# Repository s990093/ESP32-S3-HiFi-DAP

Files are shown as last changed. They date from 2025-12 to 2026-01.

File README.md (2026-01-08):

# ESP32-S3 HiFi-DAP 🎵

> **Production-Grade Digital Audio Player**  
> A professional-quality WAV music player built on ESP32 with FreeRTOS dual-core architecture.





---

## ✨ Features

### 🎵 Audiophile Edition Features

- **🎚️ Configurable Bit Depth** - 16/24/32-bit I2S output for maximum DAC compatibility
- **🧠 Dynamic Loudness** - Fletcher-Munson inspired compensation (Bass +8dB at low vol, +2dB at high vol).
- **💎 TPDF Dithering** - Triangular Probability Density Function dithering to eliminate digital quantization distortion.
- **🎚️ 3kHz AIR Treble** - Refined Treble cutoff (3000Hz) for vocal clarity without harshness.
- **🛡️ Anti-Clipping** - 0.7x digital headroom scaler to prevent soft clipping on bass hits.
- **🎯 PCM5102A Optimized** - Tuned for internal PLL usage (SCK->GND) and Charge Pump characteristics.

### 🎯 Core Features

- **🎵 Hybrid Audio Engine** - Native support for **WAV** (16-bit PCM) and **MP3** files
- **🔊 BackgroundAudio Core** - High-performance decoding with I2S DMA offloading
- **📦 Robust File Parsing** - Unified playlist handler for mixed file types
- **💾 Playback Resume** - NVS-based position persistence across power cycles
- **🎚️ Cubic Volume Control** - Enhanced low-volume precision (`vol^3` curve)
- **🔇 Pop-Free Audio** - Fade in/out on play/pause/track changes
- **🎮 Hardware Button Control** - Physical buttons with combo actions (e.g. Loop Toggle)
- **🔁 Loop Control** - Cycle loop modes: Off → Single → All via button combo
- **🚀 Startup Splash** - Animated splash screen on app launch

### 🚀 Advanced Features

- **📦 Modular Architecture** - Clean separation: Config, AudioProcessor, PlaylistManager, ButtonHandler, SerialCommands
- **⚡ FreeRTOS Dual-Core** - Core 0 for UI, Core 1 for audio processing
- **🧠 Smart Memory Management** - Fixed arrays, no heap fragmentation
- **🔍 Serial Command Interface** - Debug and control via UART (30+ commands)
- **📊 Real-Time Monitoring** - Memory usage, playback status, event logging
- **🎛️ Professional Controls** - Volume up/down, prev/next, pause/play

---

## 📋 Table of Contents

- [Desktop App](#-desktop-app-new)
- [Hardware Requirements](#hardware-requirements)
- [Pin Configuration](#pin-configuration)
- [Software Requirements](#software-requirements)
- [Installation](#installation)
- [Usage](#usage)
- [Serial Commands](#serial-commands)
- [Audio Converter Tool](#audio-converter-tool)
- [Technical Architecture](#technical-architecture)
- [Project Structure](#project-structure)
- [Troubleshooting](#troubleshooting)
- [Development](#development)
- [License](#license)

---

## 🖥️ Desktop App (NEW!)

### Apple Music-Inspired Control Center

Manage your ESP32 music player with a beautiful desktop application featuring:

- **🎨 Premium Design** - Glassmorphism, vibrant gradients, Apple Music aesthetics
- **📚 Library Management** - Browse, play, delete, and rename tracks
- **📤 File Upload** - Drag & drop MP3/WAV files to SD card
- **📊 System Diagnostics** - View real-time CPU usage, task states, and memory health (htop-style)
- **💾 Storage Monitor** - Visual SD card usage bar
- **⚡ Auto-connect** - Remembers your device

Desktop App

### Quick Start

```bash
cd desktop-app
npm install
npm start
```

👉 **[Full Desktop App Documentation →](desktop-app/README.md)**

---

## 🔧 Hardware Requirements

### Minimum Requirements

| Component | Specification |
| --- | --- |
| **MCU** | ESP32 (ESP32-WROOM, ESP32-DevKitC) |
| **Flash** | 4MB minimum |
| **SRAM** | 520KB (internal) |
| **SD Card** | Class 10+ (20MHz SPI compatible) |
| **DAC** | PCM5102A (Recommended for Audiophile Mode) |

> **⚠️ PCM5102A Critical Setup**:
> To enable the internal PLL and reduce jitter:
>
> 1. Connect **SCK** pin to **GND**.
> 2. Add **100uF + 0.1uF** capacitors near VCC for deep bass stability.

### Tested Hardware

- ✅ ESP32-DevKitC V4
- ✅ ESP32-WROOM-32D
- ✅ PCM5102A I2S DAC breakout
- ✅ SanDisk Ultra 32GB microSD (Class 10)

### Optional Components

- **Buttons** - 5x tactile switches (VOL+/-, PREV/NEXT, PAUSE)
- **Display** - (Future) TFT/OLED for UI
- **Amplifier** - External amplifier for speakers

---

## 📌 Pin Configuration

### SD Card (SPI)

| Pin  | ESP32 GPIO | Description |
| ---- | --- | --- |
| MISO | GPIO 19 | Data Out |
| MOSI | GPIO 23 | Data In |
| SCK  | GPIO 18 | Clock |
| CS | GPIO 5 | Chip Select |

### I2S DAC

| Pin | ESP32 GPIO | Description |
| --- | --- | --- |
| BCK | GPIO 4 | Bit Clock |
| WS/LRC | GPIO 15 | Word Select (L/R Clock) |
| DATA | GPIO 2 | Serial Data |

### Control Buttons

| Function | ESP32 GPIO | Description |
| --- | --- | --- |
| VOL+ | GPIO 12 | Volume Up (single press +5%, long press +1%) |
| VOL- | GPIO 13 | Volume Down (single press -5%, long press -1%) |
| PREV | GPIO 14 | Previous Track |
| NEXT | GPIO 27 | Next Track |
| PAUSE | GPIO 26 | Pause/Play (double-click = Next) |

> **Note**: All buttons use `INPUT_PULLDOWN` mode with rising edge interrupt.

---

## 💻 Software Requirements

### Development Tools

```bash
# macOS (Homebrew)
brew install arduino-cli
brew install ffmpeg  # For audio conversion

# Python dependencies
pip install rich  # For colorful CLI output
```

### Arduino Libraries (Auto-installed)

- `SPI` v3.3.3
- `SD` v3.3.3
- `FS` v3.3.3
- `Preferences` v3.3.3 (NVS)
- `BackgroundAudio` (Native ESP32 I2S Audio Library)

---

## 🚀 Installation

### 1. Clone Repository

```bash
git clone https://github.com/yourusername/ESP32-S3-HiFi-DAP.git
cd ESP32-S3-HiFi-DAP
```

### 2. Configure Board

```bash
arduino-cli config init
arduino-cli core update-index
arduino-cli core install esp32:esp32
```

### 3. Compile and Upload

```bash
# Using provided upload script
python3 scripts/upload.py src/WavPlayer --board esp32

# Or manually
arduino-cli compile --fqbn esp32:esp32:esp32 src/WavPlayer
arduino-cli upload -p /dev/cu.usbserial-* --fqbn esp32:esp32:esp32 src/WavPlayer
```

### 4. Prepare SD Card

```bash
# Format SD card as FAT32
# Copy WAV files to root directory

# Optional: Convert audio files
python3 scripts/audio_converter.py song.mp3 song.flac
```

### 5. Monitor Serial Output

```bash
python3 scripts/monitor.py /dev/cu.usbserial-* 460800
```

---

## 🎮 Usage

### Button Controls

| Action | Button | Behavior |
| --- | --- | --- |
| **Volume Up** | VOL+ (GPIO12)  | +5% per press, hold for +1%/50ms |
| **Volume Down** | VOL- (GPIO13)  | -5% per press, hold for -1%/50ms |
| **Previous Track** | PREV (GPIO14)  | Jump to previous track |
| **Next Track** | NEXT (GPIO27)  | Jump to next track |
| **Link Toggle** | PREV + NEXT | Hold both for 1s: Toggle Loop One / Loop All |
| **Pause/Play** | PAUSE (GPIO26) | Single press = toggle, double-click = next |

### First Boot

1. Insert SD card with WAV files
2. Power on ESP32
3. Wait for initialization (~3 seconds)
4. Press **PAUSE** button to start playback
5. Adjust volume with **VOL+/VOL-**

### Resume Playback

The player automatically saves:

- Current track position
- Volume level
- Play/pause state

After power cycle, it resumes from the last position.

---

## 🖥️ Serial Commands

Connect via serial terminal (460800 baud) and use these commands:

| Command | Alias | Description |
| --- | --- | --- |
| `mem` | `memory` | Show memory usage (heap, PSRAM) with visual bars |
| `tasks` | `tasks_json` | Show FreeRTOS task stats (CPU%, Stack, State) |
| `status` | `s` | Display current playback state |
| `bitdepth <n>` | - | Set I2S output bit depth (16/24/32) |
| `save` | - | Manually save playback position to NVS |
| `resume` | - | Restore playback position from NVS |
| `help` | `h`, `?` | Show command list |

### Example: Memory Status

```
mem

╔════════════════════════════════════════╗
║         Memory Status                  ║
╚════════════════════════════════════════╝
HEAP Memory:
  Total:      361400 bytes
  Used:       127416 bytes (35.3%)
  Free:       233984 bytes (64.7%)
  Min Free:   233000 bytes
  Usage: [███████░░░░░░░░░░░░░] 35.3%

PSRAM: Not available
```

---

## 🎨 Audio Converter Tool

Convert audio files to ESP32-compatible WAV format:

### Basic Usage

```bash
# Convert to WAV (default)
python3 scripts/audio_converter.py song.mp3

# Convert to FLAC (lossless archive)
python3 scripts/audio_converter.py song.mp3 --format flac

# Batch convert
python3 scripts/audio_converter.py *.mp3 --format wav
```

### Supported Formats

**Input**: MP3, M4A, AAC, FLAC, WAV, OGG, WMA, APE, ALAC  
**Output**:

- **WAV** - 16-bit PCM, 44.1kHz stereo (ESP32 playback)
- **FLAC** - Lossless, 44.1kHz stereo (archival)

See [Audio Converter Guide](docs/audio_converter_guide.md) for details.

---

## 🏗️ Technical Architecture

### FreeRTOS Dual-Core Design

```
┌─────────────────────────────────────────────────────┐
│                    ESP32 (Dual-Core)                │
├───────────────────────────┬─────────────────────────┤
│    Core 0 (Protocol CPU)  │  Core 1 (Application CPU)│
│   ┌─────────────────────┐ │ ┌──────────────────────┐│
│   │  Button Handler     │ │ │  Audio Playback      ││
│   │  - ISR Processing   │ │ │  - SD Card Reading   ││
│   │  - State Management │ │ │  - WAV Decoding      ││
│   │  - Serial Commands  │ │ │  - Volume Control    ││
│   │  - UI Updates       │ │ │  - I2S Streaming     ││
│   └─────────────────────┘ │ └──────────────────────┘│
│          Priority: 1       │       Priority: 2       │
└───────────────────────────┴─────────────────────────┘
                      │
              ┌───────┴────────┐
              │  Shared State  │
              │  (Mutex-locked)│
              └────────────────┘
```

### Audio Pipeline

```
SD Card → Chunk Parser → Volume Control → Fade In/Out → I2S DMA → DAC → Headphones/Speakers
         (20MHz SPI)    (Logarithmic)    (2048 samples)  (8x1024)
```

### Key Technologies

- **BackgroundAudio Lib** - Core decoding engine for MP3/WAV
- **Chunk-Based Feeding** - Efficient buffer management
- **Cubic Volume Curve** - `pow(vol, 3)` calculation for 10-bit dynamic range
- **NVS (Non-Volatile Storage)** - Flash-based state persistence
- **Hybrid Task Pattern** - Core 0 (UI/Control) + Core 1 (Audio Decoding)

---

## 📁 Project Structure

```
ESP32-S3-HiFi-DAP/
├── src/
│   └── WavPlayer/
│       ├── WavPlayer.ino          # Main firmware (~350 lines)
│       ├── Config.h               # Global configuration
│       ├── AudioProcessor.h/.cpp  # EQ, dithering, bit depth
│       ├── PlaylistManager.h/.cpp # Playlist scanning
│       ├── ButtonHandler.h/.cpp   # Button ISRs, NVS
│       └── SerialCommands.h/.cpp  # Serial interface
├── desktop-app/                   # 🆕 Desktop Control Center
│   ├── src/
│   │   ├── main.js                # Electron main process
│   │   ├── renderer.js            # UI logic (383 lines)
│   │   ├── styles.css             # Apple-style CSS (600+ lines)
│   │   ├── index.html             # Main interface
│   │   └── demo.html              # Standalone demo
│   ├── package.json
│   └── README.md                  # Desktop app docs
├── scripts/
│   ├── audio_converter.py         # Audio format converter
│   ├── upload.py                  # Build & upload tool
│   └── monitor.py                 # Serial monitor
├── docs/
│   ├── architecture.md            # System architecture
│   ├── wav_player_guide.md        # User guide
│   └── audio_converter_guide.md   # Converter manual
└── README.md                      # This file
```

---

## 🐛 Troubleshooting

### SD Card Not Detected

```
❌ SD Card failed!
```

**Solutions**:

1. Check wiring (MISO/MOSI/SCK/CS)
2. Ensure SD card is FAT32 formatted
3. Try reducing SPI speed to 10MHz in code:
   ```cpp
   SD.begin(SD_CS, SPI, 10000000);  // Change from 20MHz
   ```

### Audio Stuttering

**Causes**:

- Slow SD card (< Class 10)
- Corrupted WAV file
- Insufficient power supply

**Solutions**:

1. Use Class 10+ SD card
2. Re-convert WAV files:
   ```bash
   python3 scripts/audio_converter.py file.wav
   ```
3. Connect 5V/1A power supply (not USB)

### No Audio Output

**Check**:

1. DAC connections (BCK, WS, DATA)
2. DAC power supply (3.3V or 5V depending on model)
3. Headphone/speaker connection
4. Volume level (`status` command should show > 0%)

### Playback Not Resuming

```bash
# Reset NVS storage
save   # First save current state
resume # Then restore
```

If issue persists, reflash ESP32.

---

## 🛠️ Development

### Debug Mode

Enable detailed logging in `WavPlayer.ino`:

```cpp
#define DEBUG_ENABLED 1  // Set to 0 to disable
```

Output includes:

- WAV chunk parsing details
- File scanning progress
- Task creation status
- Event logs for all actions

### Performance Tuning

```cpp
// Adjust DMA buffer for lower latency
.dma_buf_count = 4,    // Default: 8
.dma_buf_len = 512,    // Default: 1024

// Increase SPI speed (if stable)
SD.begin(SD_CS, SPI, 40000000);  // 40MHz (risky)
```

### Adding New Features

1. **EQ (Equalizer)** - Apply DSP filters in `applyVolume()`
2. **Shuffle Mode** - Randomize `playlist[]` order
3. **Gapless Playback** - Pre-buffer next track
4. **Display Support** - Add TFT/OLED in `buttonHandlerTask`

---

## 📊 Performance Metrics

| Metric | Value |
| --- | --- |
| Flash Usage | 486KB (15.4%) |
| SRAM Usage | 30KB (9.3%) |
| Boot Time | ~3 seconds |
| Track Change Latency | <100ms |
| Button Response | <10ms (ISR) |
| Audio Latency | ~46ms (buffer) |
| Max Tracks Supported | 32 (configurable) |

---

## 🤝 Contributing

Contributions welcome! Please:

1. Fork the repository
2. Create a feature branch (`git checkout -b feature/amazing-feature`)
3. Commit changes (`git commit -m 'Add amazing feature'`)
4. Push to branch (`git push origin feature/amazing-feature`)
5. Open a Pull Request

---

## 📄 License

This project is licensed under the MIT License - see [LICENSE](LICENSE) file for details.

---

## 🙏 Acknowledgments

- **Espressif** - ESP32 platform and Arduino core
- **Hackaday** - I2S configuration reference
- **FreeRTOS** - Real-time operating system
- Community contributors and testers

---

## 📞 Contact

**Project**: [ESP32-S3-HiFi-DAP](https://github.com/yourusername/ESP32-S3-HiFi-DAP)  
**Issues**: [GitHub Issues](https://github.com/yourusername/ESP32-S3-HiFi-DAP/issues)  
**Documentation**: [Wiki](https://github.com/yourusername/ESP32-S3-HiFi-DAP/wiki)

---

<p align="center">
  Made with ❤️ for audiophiles and makers
</p>

<p align="center">
  <sub>If you found this project useful, please consider giving it a ⭐!</sub>
</p>

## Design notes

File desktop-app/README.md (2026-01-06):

# ESP32 Music Center - Desktop App 🎵

> **Apple Music-Inspired Control Center for ESP32 HiFi-DAP**  
> A beautiful Electron-based desktop application for managing your ESP32 music player.





---

## ✨ Features

### 🎨 Premium Apple Music Design

- **Glassmorphism Effects** - Backdrop blur and translucent layers
- **Vibrant Gradients** - Purple-pink-blue accent colors
- **Premium Typography** - Inter font (SF Pro-like)
- **Smooth Animations** - Micro-interactions and transitions
- **Enhanced Player Bar** - 120px tall with album art and progress bar

### 🎮 Music Management

- 📚 **Library View** - Browse all tracks on SD card
- ▶️ **Playback Controls** - Play, pause, next, previous
- 📤 **File Upload** - Drag & drop MP3/WAV files
- 🗑️ **File Management** - Delete and rename tracks
- 📊 **Real-time Status** - Track info, volume, system stats

### 🔧 Device Control

- 🔌 **Auto-Connect** - Remembers last connected device
- 📡 **Serial Communication** - 460800 baud UART
- 💾 **SD Storage Monitor** - Visual storage usage bar
- ⚙️ **Settings Panel** - Configure buffer size and preferences

---

## 📸 Screenshots

### Main Interface

Full Interface

### Hover Effects

Hover State

---

## 🚀 Quick Start

### Prerequisites

```bash
# Install Node.js (v16+)
brew install node    # macOS
# Or download from https://nodejs.org

# Verify installation
node --version
npm --version
```

### Installation

```bash
# Navigate to desktop-app directory
cd desktop-app

# Install dependencies
npm install

# Start the application
npm start
```

---

## 📋 Usage Guide

### First Launch

1. **Connect ESP32**

   - Plug in your ESP32 via USB
   - The app will auto-scan for serial ports
   - Select your device and click "Connect"

2. **Browse Library**

   - The library view shows all tracks on SD card
   - Click any track to start playback
   - Hover to see delete button

3. **Upload Music**
   - Switch to "Upload" view
   - Drag & drop MP3/WAV files
   - Or click to browse files

### Controls

| Action | Method |
| --- | --- |
| **Play Track** | Click on track in library |
| **Play/Pause** | Click center play button (⏸/▶) |
| **Next Track** | Click next button (⏭) |
| **Previous Track**  | Click previous button (⏮) |
| **Delete Track** | Hover track → Click 🗑️ button |
| **Rename Track** | Double-click track name → Edit → Enter |
| **Upload File** | Drag & drop to upload zone |
| **Refresh Library** | Click "🔄 Refresh List" |

---

## 🏗️ Architecture

### Tech Stack

- **Framework**: Electron (v39.2.7)
- **IPC**: Serial communication via SerialPort
- **UI**: HTML5 + Vanilla CSS + JavaScript
- **Font**: Inter (Google Fonts)
- **Design**: Apple Music-inspired glassmorphism

### File Structure

```
desktop-app/
├── src/
│   ├── main.js          # Electron main process
│   ├── preload.js       # Context bridge
│   ├── renderer.js      # UI logic (383 lines)
│   ├── index.html       # Main UI
│   ├── styles.css       # Apple-style CSS (600+ lines)
│   └── demo.html        # Standalone demo
├── package.json
└── README.md            # This file
```

### Serial Protocol

The app communicates with ESP32 via JSON commands:

```javascript
// Status Request
"status_json"

// Response
{
  "state": "playing",
  "file": "/song.mp3",
  "track_index": 2,
  "track_total": 15,
  "volume": 35
}

// File List Request
"list_json"

// Response
{
  "files": [
    {"name": "/song1.mp3", "size": 5242880},
    {"name": "/song2.mp3", "size": 7340032}
  ]
}
```

---

## 🎨 Design System

### Color Palette

```css
/* Dark Background */
--bg-primary: #0a0a0f;
--bg-secondary: #1a1a24;

/* Glassmorphism */
--glass-bg: rgba(30, 30, 45, 0.7);
backdrop-filter: blur(40px);

/* Vibrant Accents */
--accent-gradient: linear-gradient(
  135deg,
  #667eea 0%,
  #764ba2 50%,
  #f093fb 100%
);
```

### Typography

```css
font-family: "Inter", -apple-system, BlinkMacSystemFont, "Segoe UI";
-webkit-font-smoothing: antialiased;
letter-spacing: -0.3px to -0.5px;
```

### Animations

- **Fade In**: 0.5s ease on page load
- **Slide Up**: 0.3s for modals
- **Pulse**: 2s infinite for play indicator
- **Glow**: 3s infinite for album art
- **Hover Scale**: 0.2s cubic-bezier for buttons

---

## 🛠️ Development

### Running in Dev Mode

```bash
# Install dependencies
npm install

# Start with hot reload (if using electron-reloader)
npm start

# Or run directly
npx electron .
```

### Building for Production

```bash
# Package for macOS
npx electron-packager . "ESP32 Music Center" --platform=darwin --arch=x64

# Package for Windows
npx electron-packager . "ESP32 Music Center" --platform=win32 --arch=x64

# Package for Linux
npx electron-packager . "ESP32 Music Center" --platform=linux --arch=x64
```

### Debug Mode

Open DevTools with:

- **macOS**: `Cmd + Option + I`
- **Windows/Linux**: `Ctrl + Shift + I`

---

## 🐛 Troubleshooting

### App Won't Start

```bash
# Clear node_modules and reinstall
rm -rf node_modules package-lock.json
npm install
npm start
```

### Serial Port Not Found

1. Check USB connection
2. Verify ESP32 is powered on
3. Click "Rescan" in connection modal
4. Check permissions (macOS may require):
   ```bash
   sudo chmod 666 /dev/cu.usbserial-*
   ```

### Upload Fails

- Ensure ESP32 is connected and idle
- Check SD card has free space
- Try smaller files first (\<10MB)
- Reduce upload chunk size in `main.js`:
  ```javascript
  const CHUNK_SIZE = 4096; // Default: 8192
  ```

### No Status Updates

1. Check serial baud rate (should be 460800)
2. Verify ESP32 firmware supports JSON commands
3. Monitor serial output in DevTools console

---

## 📡 Serial Commands Reference

| Command | Response | Description |
| --- | --- | --- |
| `status_json` | JSON | Current playback status |
| `list_json` | JSON | File list with sizes |
| `sys_json` | JSON | System stats (heap, uptime) |
| `info_json` | JSON | Device info (name, version) |
| `play <file>` | - | Play specific file |
| `pause` | - | Pause playback |
| `resume` | - | Resume playback |
| `next` | - | Next track |
| `prev` | - | Previous track |
| `delete <file>` | - | Delete file from SD |
| `rename <old> <new>` | - | Rename file |
| `upload <path> <size>` | READY | Start file upload |

---

## 🎯 Features Roadmap

### v2.0 (Current)

- ✅ Apple Music-inspired design
- ✅ Glassmorphism effects
- ✅ File upload/delete/rename
- ✅ Real-time status updates
- ✅ SD storage monitoring

### v2.1 (Planned)

- [ ] Album artwork display
- [ ] Seekbar functionality
- [ ] Volume slider control
- [ ] Playlist management
- [ ] Dark/Light theme toggle

### v3.0 (Future)

- [ ] Bluetooth streaming control
- [ ] EQ settings panel
- [ ] Lyrics display
- [ ] Multi-device support
- [ ] Cloud sync

---

## 🤝 Contributing

Contributions are welcome! To contribute:

1. Fork the repository
2. Create a feature branch
3. Make your changes
4. Test on macOS/Windows/Linux
5. Submit a pull request

### Code Style

- Use 2-space indentation
- Follow existing naming conventions
- Add comments for complex logic
- Test serial communication thoroughly

---

## 📄 License

MIT License - see [LICENSE](../LICENSE) file for details.

---

## 🙏 Credits

- **Design Inspiration**: Apple Music
- **Icons**: Unicode emoji
- **Font**: Inter by Rasmus Andersson
- **Framework**: Electron by GitHub

---

<p align="center">
  Made with ❤️ for ESP32 audiophiles
</p>

<p align="center">
  <sub>Part of the ESP32-S3-HiFi-DAP project</sub>
</p>

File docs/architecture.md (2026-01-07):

# ESP32-S3 Hi-Fi Digital Audio Player - System Architecture

> **Version:** 2.1
> **Last Updated:** 2026-01-06
> **Device:** TTGO T-Display S3 (ESP32-S3) / Classic ESP32

## 1. System Overview (系統總覽)

This project implements a high-fidelity digital audio player (DAP) capabilities on the ESP32 platform. It features a unique **Hybrid Bluetooth Architecture** that allows it to function as both a device scanner (central) and a high-quality audio source (A2DP Source) seamlessly.

### Key Features

- **Dual-Core Processing**: Dedicated cores for Audio/Bluetooth (Core 1) and System/UI (Core 0).
- **Hybrid Bluetooth**: Intelligent coexistence between GAP Scanning and A2DP Streaming.
- **High-Resolution Audio**: Supports WAV playback from SD Card via I2S.
- **Interactive UI**: TFT Display integration with physical button controls.

---

## 2. Architecture Diagram (系統架構圖)

The system is layered to separate hardware abstraction, logic management, and application control.

```mermaid
graph TD
    subgraph "Hardware Layer"
        ESP[ESP32-S3 SoC]
        SD[SD Card (SPI)]
        DAC[I2S DAC / Bluetooth]
        TFT[TFT Display (SPI)]
        BTN[Buttons (GPIO)]
    end

    subgraph "Driver / HAL Layer"
        SD_HAL[sd_card.cpp]
        DISP_HAL[display.cpp]
        BTN_HAL[button_handler.cpp]
        BT_STACK[ESP-IDF Bluetooth Stack]
    end

    subgraph "Manager Layer"
        BT_MGR[Bluetooth Manager (Scanner)]
        A2DP[A2DP Source (Streamer)]
        PLAY[Audio Player (Logic)]
    end

    subgraph "Application Layer"
        MAIN[Main Loop (Arduino)]
        UI[UI Controller]
        CMD[Serial Command Interface]
    end

    %% Connections
    BTN --> BTN_HAL --> MAIN
    MAIN --> UI --> DISP_HAL --> TFT
    MAIN --> CMD

    MAIN --> PLAY
    PLAY --> SD_HAL --> SD
    PLAY --> A2DP

    MAIN --> BT_MGR
    BT_MGR -- "Inquiry" --> BT_STACK --> ESP
    A2DP -- "Audio Stream" --> BT_STACK --> ESP
```

---

## 3. Subsystem Detail (子系統詳解)

### 3.1 Audiophile DSP Pipeline (Core 1)

The "Audiophile Edition" uses a dedicated `AudioOutputWithEQ` class that inherits from `ESP32I2SAudio`. This ensures a unified processing chain for **both** WAV and MP3 formats.

**Signal Path:**

```
[ Decoder Output (WAV/MP3) ]
         │
         ▼
[ 1. Headroom Scaler ]  <-- Multiplies by 0.707 (-3dB)
         │
         ▼
[ 2. Dynamic EQ Engine ] <-- **NEW**: Variable Gain based on Volume
         │                   (Low Vol: +8dB Bass / +4dB Treble)
         │                   (High Vol: +2dB Bass / +1dB Treble)
         ▼
[ 3. TPDF Dithering ]   <-- Adds triangular noise
         │
         ▼
[ 4. Hard Limiter ]     <-- Clamps values
         │
         ▼
[ I2S DMA Buffer ]
         │
         ▼
[ PCM5102A DAC ]
```

**Key Class:**

```cpp
class AudioOutputWithEQ : public ESP32I2SAudio {
    virtual size_t write(const uint8_t *buffer, size_t size) override {
        // Intercepts all audio data here for DSP processing
    }
}
```

### 3.2 Hybrid Bluetooth Architecture (藍牙混合架構)

This is the most complex part of the system, solving the "Scanner vs Streamer" conflict.

- **State A: Scanning (Discovery)**

  - **Module**: `bluetooth_manager.cpp`
  - **Action**: Uses `esp_bt_gap_start_discovery` to find peripherals.
  - **Restriction**: Audio streaming is paused to dedicate radio time to scanning.
  - **Data**: POPULATES a list of nearby `bt_device_t`.

- **State B: Streaming (A2DP)**

  - **Module**: `bt_audio_stream.cpp`
  - **Action**: Connects to a specific MAC address using `BluetoothA2DPSource`.
  - **Priority**: High real-time priority. Scanning is disabled.

- **Coexistence Logic**: The system checks `bluetooth_is_connected()`. If connected, SCAN commands are rejected or deferred to prevent audio dropouts.

---

## 4. Software Modules (軟體模組說明)

| Module | File | Responsibility | Core Affinity |
| :--- | :--- | :--- | :--- |
| **Main** | `ESP32-S3-HiFi-DAP.ino` | Entry point, setup, main loop, event dispatching. | Core 1 (Arduino) |
| **Audio** | `audio_player.cpp` | State machine (PLAY/PAUSE/STOP), playlist management. | Core 1 |
| **SD** | `sd_card.cpp` | SPI file system mounting, file scanning, raw reading. | Core 0 (I/O) |
| **Bluetooth** | `bluetooth_manager.cpp` | GAP scanning, device list management. | Core 1 |
| **A2DP** | `bt_audio_stream.cpp` | A2DP source implementation, audio callbacks. | Core 0 (Stack) |
| **Display** | `display.cpp` | TFT rendering, progress bars, cover art (future). | Core 1 |
| **Serial** | `serial_manager.cpp` | PC communication protocol handling. | Core 1 |

---

## 5. Directory Structure (目錄結構)

```text
ESP32-S3-HiFi-DAP/
├── ESP32-S3-HiFi-DAP.ino    # Main Application application
├── config.h                 # Global Configuration (Pins, Settings)
├── docs/                    # Documentation
│   ├── architecture.md      # This file
│   ├── remote_control.md    # Serial Protocol
│   └── pin_map.md           # Hardware Wiring
├── scripts/                 # Host-side Tools
│   ├── upload.py            # Build & Upload Tool
│   ├── monitor.py           # Serial Monitor
│   └── convert_audio.sh     # Audio preparation
├── src/                     # (Optional) Source folder if migrated
├── libraries/               # Local library overrides
└── partitons.csv            # Partition Scheme (App/Data/Factory)
```

## 6. Memory Map (Partition Scheme)

We use a custom `huge_app` partition scheme to accommodate the Bluetooth stack.

| Name | Type | SubType | Offset  | Size |
| :--- | :--- | :--- | :--- | :--- |
| nvs | data | nvs | 0x9000  | 20KB |
| otadata | data | ota | 0xe000  | 8KB |
| app0 | app  | ota_0 | 0x10000 | **3MB** (Large App) |
| spiffs  | data | spiffs  | ... | 1MB (Assets) |

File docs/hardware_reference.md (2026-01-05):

# Hardware Reference

## Device Setup: **TTGO T-Display S3** / Custom ESP32 Board

## Pin Configuration (`config.h`)

### SD Card (SPI)

| Signal | GPIO (VSPI) | Notes |
| :--- | :--- | :--- |
| **CS** | 5 | Chip Select |
| **MOSI** | 23 | Master Out Slave In |
| **MISO** | 19 | Master In Slave Out |
| **SCK**  | 18 | Serial Clock |

### I2S DAC Configuration (PCM5102A)

The Audiophile Edition is strictly tuned for the **PCM5102A** DAC.

| Pin Name | ESP32 GPIO | Function | Note |
| :--- | :--- | :--- | :--- |
| **BCK** | GPIO 4 | Bit Clock | |
| **WS** | GPIO 15 | Word Select  | |
| **DATA** | GPIO 2 | Data In | |
| **SCK** | **GND** | System Clock | **CRITICAL**: Grounding SCK forces internal PLL mode |
| **VCC** | 5V / 3.3V  | Power | **rec:** Add 100uF + 0.1uF caps for stability |
| Left/Right Clock (WS) |
| **DOUT** | 4 | Data Out |

### OLED Display (I2C) - New

| Signal  | GPIO | Notes |
| :--- | :--- | :--- |
| **SDA** | 21 | Serial Data  |
| **SCL** | 22 | Serial Clock |

### User Interface

| Button | GPIO | Active State  |
| :--- | :--- | :--- |
| **Prev** | 32 | Low (Pull-up) |
| **Next** | 33 | Low (Pull-up) |
| **Play** | 25 | Low (Pull-up) |
| **Stop** | 26 | Low (Pull-up) |

## Partition Scheme

We use a custom `huge_app` partition scheme to enable large Bluetooth stacks.

**File:** `partitions.csv`

```csv
# Name,   Type, SubType, Offset,  Size, Flags
nvs,      data, nvs,     0x9000,  0x5000,
otadata,  data, ota,     0xe000,  0x2000,
app0,     app,  ota_0,   0x10000, 0x300000, # 3MB for Application
spiffs,   data, spiffs,  0x310000,0x100000, # 1MB for Files
```

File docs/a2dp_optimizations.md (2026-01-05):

# A2DP 性能優化說明

## 已應用的優化

### 1. 自動重連功能 ✅

```cpp
a2dp_source.set_auto_reconnect(true);
```

**效果**：當藍牙連接意外斷開時，ESP32 會自動嘗試重新連接到上次配對的設備。

**適用場景**：

- 設備暫時移出範圍又回來
- 藍牙干擾導致的短暫斷線
- 提升用戶體驗，無需手動重連

---

### 2. 低延遲配置 (庫版本相關)

```cpp
// 這些方法在 ESP32-A2DP 某些版本可能不可用
a2dp_source.set_max_write_size(2048);      // 設置最大寫入塊大小
a2dp_source.set_max_write_delay_ms(5);     // 設置最大寫入延遲
```

**注意**：這些方法已註釋，因為：

- 不是所有版本的 `ESP32-A2DP` 庫都支持
- 需要根據實際庫版本調整
- 如果編譯報錯，可以移除這些行

**如何啟用**：

1. 檢查你的 ESP32-A2DP 庫版本（目前是 1.8.8）
2. 查看庫的 API 文檔確認是否支持
3. 取消註釋測試

---

## 其他可用的優化

### 3. Buffer 大小調整

當前配置：

- ESP32 (無 PSRAM): 16KB
- ESP32-S3 (有 PSRAM): 64KB

**調整建議**：

```h
// config.h
#define AUDIO_RING_BUFFER_SIZE  (32 * 1024)  // 增大 buffer 減少 underrun
```

### 4. SPI 頻率優化

當前 SD 卡：10MHz

**可嘗試**：

```c
// sd_card.c
uint32_t frequencies[] = {20000000, 10000000};  // 先試 20MHz
```

### 5. FreeRTOS 任務優先級

當前配置：

```h
#define TASK_SD_READ_PRIORITY   5
#define TASK_BT_TX_PRIORITY     20  // 最高優先級給音訊
```

**已優化** ✅

---

## 測試建議

1. **測試自動重連**：

   - 播放音樂時關閉藍牙耳機
   - 重新打開耳機
   - 觀察是否自動重連

2. **測試音訊穩定性**：

   - 長時間播放（1 小時+）
   - 監控 `buffer_underruns` 計數
   - 檢查序列埠輸出的 "BUFFER EMPTY" 警告

3. **測試範圍**：
   - 逐漸增加 ESP32 與耳機距離
   - 觀察斷線重連表現

---

## 參考資料

- [ESP32-A2DP GitHub](https://github.com/pschatzmann/ESP32-A2DP)
- [A2DP 優化文檔](docs/bluetooth_architecture.md)

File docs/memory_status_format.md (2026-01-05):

# Memory Status Command Format

## Response Format

```
OK:HEAP|free|total|used%|free%|min_free|max_alloc|PSRAM|free|total|used%|free%
```

### HEAP Section

- **free**: 當前可用堆記憶體 (bytes)
- **total**: 總堆記憶體 (bytes)
- **used%**: 已使用百分比
- **free%**: 剩餘百分比
- **min_free**: 開機以來最低可用記憶體 (bytes)
- **max_alloc**: 最大可分配塊大小 (bytes)

### PSRAM Section

- **free**: 當前可用 PSRAM (bytes)
- **total**: 總 PSRAM (bytes)
- **used%**: 已使用百分比
- **free%**: 剩餘百分比

### 範例輸出

**有 PSRAM (ESP32-S3)**:

```
OK:HEAP|250000|327680|23.7|76.3|200000|180000|PSRAM|3800000|4194304|9.4|90.6
```

**無 PSRAM (ESP32 標準版)**:

```
OK:HEAP|58604|244680|76.0|24.0|53876|47092|PSRAM|0|0|0.0|0.0
```

## Debug Console Output

MEM 命令同時會輸出詳細訊息到序列埠：

```
--- Memory Status ---
[Heap] Free: 58604/244680 bytes (24.0% free, 76.0% used)
[Heap] Min Free: 53876, Max Alloc: 47092
[PSRAM] Not available

[Internal RAM]
Heap summary for capabilities 0x00000800:
  At 0x3ffaff10 len 240 free 8 allocated 4 min_free 8
    largest_free_block 0 alloc_blocks 1 free_blocks 1 total_blocks 2
  ...
```

## 警告標準

### 記憶體不足警告

- **Critical**: free_heap < 10KB
- **Warning**: free_heap < 20KB
- **Fragmentation**: largest_free_block << free_heap

### PSRAM 使用

- ESP32 標準版: 無 PSRAM (總是顯示 0)
- ESP32-S3: 通常有 2MB, 4MB, 或 8MB PSRAM

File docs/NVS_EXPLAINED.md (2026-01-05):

# NVS 儲存機制說明

## 🔍 什麼是 NVS？

**NVS** = **Non-Volatile Storage** (非揮發性儲存)

這是 ESP32 內建的一個特殊 **Flash 記憶體分區**，用來永久儲存資料。

### 📍 NVS 存在哪裡？

```
ESP32 Flash Memory (4MB)
├── Bootloader      (0x1000)
├── Partition Table (0x8000)
├── NVS             (0x9000)  ← 在這裡！
├── OTA Data        (0xE000)
└── App (Firmware)  (0x10000)
```

**實體位置**：

- **晶片內部 Flash**（與程式碼同一顆 IC）
- **分區起始位址**：0x9000
- **大小**：通常 20KB (0x5000 bytes)
- **特性**：斷電不會消失（像 EEPROM）

---

## 📦 我們儲存了什麼？

### 儲存內容

使用 ESP32 的 `Preferences` 庫，命名空間為 `"wavplayer"`：

| 鍵 (Key)  | 類型 | 範例值 | 說明 |
| --- | ---- | --- | --- |
| `track` | int  | 2 | 當前曲目索引 (0-31) |
| `volume`  | int  | 30 | 音量 (0-100%) |
| `playing` | bool | false  | 是否正在播放 |

### 程式碼實作

```cpp
// 儲存狀態到 NVS
void savePlaybackState() {
  prefs.begin("wavplayer", false);  // 開啟命名空間（可寫）
  prefs.putInt("track", currentTrack);
  prefs.putInt("volume", currentVolume);
  prefs.putBool("playing", playbackState == STATE_PLAYING);
  prefs.end();

  DEBUG_PRINTLN("💾 State saved to NVS");
}

// 從 NVS 載入狀態
void loadPlaybackState() {
  prefs.begin("wavplayer", true);  // 開啟命名空間（唯讀）
  currentTrack = prefs.getInt("track", 0);      // 預設值 0
  currentVolume = prefs.getInt("volume", 30);   // 預設值 30
  bool wasPlaying = prefs.getBool("playing", false);
  prefs.end();

  if (wasPlaying) {
    Serial.println("🔄 Resuming from last session");
  }
}
```

---

## 🔄 Resume 指令的作用

### 自動 vs 手動

#### 1️⃣ **自動載入**（開機時）

程式在 `setup()` 中會**自動執行**：

```cpp
void setup() {
  // ...
  loadPlaybackState();  // ← 自動載入！
  // ...
}
```

**開機流程**：

```
ESP32 啟動
    ↓
執行 setup()
    ↓
loadPlaybackState() ← 自動從 NVS 讀取
    ↓
顯示: 🔄 Resuming from last session
       Track: 2, Volume: 30%
    ↓
繼續播放
```

#### 2️⃣ **手動 Resume**（Serial 指令）

在程式運行中，你可以手動執行：

```bash
resume
```

**作用**：

- 重新從 NVS 讀取儲存的狀態
- 覆蓋當前的 runtime 狀態
- 用於「回到上次儲存的狀態」

**使用場景範例**：

```bash
# 場景 1：測試用
status          # Track: 5, Volume: 50%
save            # 儲存當前狀態

# 然後你手動改變狀態
(按 NEXT 幾次，音量調到 80%)
status          # Track: 8, Volume: 80%

resume          # 恢復到儲存的狀態
status          # Track: 5, Volume: 50% (回到剛才儲存的)

# 場景 2：意外改變後恢復
(不小心按了很多次 NEXT)
resume          # 回到上次自動儲存的狀態
```

---

## 🔁 自動儲存時機

系統會在以下情況**自動執行** `savePlaybackState()`：

### 觸發條件

| 事件 | 延遲 | 位置 |
| --- | --- | --- |
| 曲目改變 (PREV/NEXT) | 立即 | `buttonHandlerTask` |
| 音量改變 (VOL+/-) | 立即 | `buttonHandlerTask` |
| 暫停/播放切換 | 立即 | `buttonHandlerTask` |
| 背景定時器 | 每 30 秒 | `buttonHandlerTask` |

### 程式碼位置

```cpp
// buttonHandlerTask (Core 0)
void buttonHandlerTask(void* parameter) {
  static unsigned long lastSave = 0;

  while (true) {
    // ... 按鈕處理 ...

    switch (i) {
      case 0: // VOL+
        currentVolume = min(100, currentVolume + 5);
        savePlaybackState();  // ← 立即儲存
        break;

      case 3: // NEXT
        currentTrack = (currentTrack + 1) % playlistSize;
        trackChanged = true;
        // 在 audioPlaybackTask 中會執行 savePlaybackState()
        break;
    }

    // 背景自動儲存（每 30 秒）
    if (millis() - lastSave > 30000) {
      savePlaybackState();  // ← 定時儲存
      lastSave = millis();
    }
  }
}
```

---

## 💾 NVS 寫入次數限制

### Flash 壽命

ESP32 的 Flash 有寫入次數限制：

- **理論壽命**：~100,000 次寫入/抹除（每個扇區）
- **實際壽命**：通常更高（150,000+）

### 我們的使用情況

**每日估算**：

```
假設每天使用 8 小時
- 背景儲存：8小時 * 2次/分鐘 = 960次/天
- 換曲儲存：平均 50次/天
- 音量調整：平均 20次/天
────────────────────────────────
總計：~1,030 次/天
```

**壽命計算**：

```
100,000 次 ÷ 1,030 次/天 = 97 天
```

### 😱 會不會太快壞掉？

**不會！** 原因：

1. **Wear Leveling**（磨損平衡）
   - ESP32 的 NVS 系統自動分散寫入
   - 不會總是寫同一個位置
2. **實際壽命更長**

   - Flash 實際可承受更多次數
   - 通常可用 1-2 年

3. **優化建議**

如果擔心壽命，可以調整背景儲存頻率：

```cpp
// 改為 5 分鐘儲存一次
if (millis() - lastSave > 300000) {  // 300秒 = 5分鐘
  savePlaybackState();
  lastSave = millis();
}
```

這樣壽命延長到：

```
100,000 ÷ (8*12 + 70) = 100,000 ÷ 166 = 602 天 (1.6年)
```

---

## 🔍 查看 NVS 內容

### 使用 `nvs` 指令

```bash
nvs

╔════════════════════════════════════════╗
║         NVS Storage (Flash)            ║
╚════════════════════════════════════════╝

💾 Stored Preferences:
  Track Index:   2           ← Flash 中儲存的
  Track File:    /song3.wav
  Volume:        30%
  Was Playing:   No

📋 Current Runtime State:
  Track Index:   5           ← RAM 中運行的
  Track File:    /song6.wav
  Volume:        50%
  State:         Playing

⚙️  NVS Operations:
  Auto-save triggers:
    - Track change
    - Volume change
    - Pause/Play toggle
    - Every 30 seconds (background)
```

**解讀**：

- **Stored Preferences** = Flash 中永久儲存的值
- **Current Runtime State** = RAM 中當前運行的值
- 如果兩者不同，表示還沒儲存，或執行 `resume` 會回到 Stored 狀態

---

## 🗑️ 清除 NVS（重置）

如果想清除所有儲存資料：

### 方法 1：程式碼清除

在 Serial 中可以加入清除指令（目前未實作）：

```cpp
// 可以加入這個指令
else if (cmd == "clear" || cmd == "reset") {
  prefs.begin("wavplayer", false);
  prefs.clear();  // 清除所有 key
  prefs.end();
  Serial.println("✅ NVS cleared");
}
```

### 方法 2：手動抹除（esptool）

```bash
esptool.py --port /dev/cu.usbserial-1140 erase_region 0x9000 0x5000
```

### 方法 3：重刷 Partition Table

完整重刷韌體會重置 NVS。

---

## 📊 NVS vs 其他儲存方式

| 方式 | 位置 | 大小  | 速度 | 斷電保存 | 寫入次數 |
| --- | --- | ----- | ---- | --- | --- |
| **NVS** | Flash | 20KB  | 中等 | ✅ 是 | ~100K |
| **SPIFFS/LittleFS** | Flash | 自訂  | 慢 | ✅ 是 | ~100K |
| **SD Card** | 外部 | GB 級 | 慢 | ✅ 是 | 極高 |
| **RAM** | 內部 SRAM  | 320KB | 極快 | ❌ 否 | 無限 |
| **EEPROM** | (ESP32 無) | - | - | - | - |

**為什麼選 NVS？**

- ✅ 斷電保存
- ✅ 快速讀寫
- ✅ 內建支援（無需外部硬體）
- ✅ ESP32 官方推薦
- ✅ 自動 wear leveling

---

## 🧪 實驗測試

### 測試 1：驗證斷電保存

```bash
# 1. 設定狀態
(按 NEXT 到 Track 3, 音量調到 40%)
save

# 2. 查看儲存
nvs
# 應該顯示 Track: 3, Volume: 40%

# 3. 斷電重啟
(拔電源，再插回)

# 4. 查看啟動訊息
# 應該看到：
# 🔄 Resuming from last session
#    Track: 3, Volume: 40%
```

### 測試 2：Resume 指令

```bash
# 1. 儲存當前狀態
status  # Track: 2
save

# 2. 改變狀態
(按 NEXT NEXT NEXT)
status  # Track: 5

# 3. 執行 resume
resume

# 4. 確認恢復
status  # Track: 2 (恢復了！)
```

---

## 🎯 總結

### Resume 指令

- **作用**：從 NVS 讀取上次儲存的播放狀態
- **使用時機**：想恢復到之前儲存的狀態時
- **效果**：覆蓋當前 RAM 中的狀態

### NVS 儲存位置

- **實體位置**：ESP32 Flash 晶片內部（0x9000）
- **邏輯位置**：命名空間 "wavplayer"
- **儲存內容**：track, volume, playing (共 3 個鍵值對)
- **壽命**：約 100,000 次寫入

### 工作流程

```
開機
  ↓
自動 loadPlaybackState() ← 從 NVS 讀取
  ↓
正常使用（改變音量、曲目等）
  ↓
自動 savePlaybackState() ← 寫入 NVS
  ↓
斷電
  ↓
重新開機
  ↓
自動恢復到上次狀態 ✅
```

**手動介入**：

```
正在播放 Track 5
  ↓
輸入 "resume"
  ↓
恢復到 NVS 中儲存的狀態（例如 Track 2）
```

簡單來說：**NVS 就像是 ESP32 的「存檔點」，resume 就是「讀取存檔」！** 🎮

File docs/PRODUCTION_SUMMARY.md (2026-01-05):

# 🎉 Production-Grade WAV Player - 最終版本

## 📊 升級完成總結

**版本**: v2.0 Production  
**上傳時間**: 2026-01-01 14:46  
**Flash 使用**: 381,984 bytes (12.15%)  
**狀態**: ✅ 穩定運行

---

## 🆕 新增功能

### 1. **Serial 指令系統**

| 指令 | 別名 | 功能 |
| --- | --- | --- |
| `mem` | `memory` | 顯示記憶體使用率（含視覺化圖表） |
| `status` | `s` | 顯示播放器狀態 |
| `settings` | `config` | 顯示系統設定 |
| `nvs` | `read` | 顯示 NVS 儲存狀態 |
| `tree` | `ls` | 列出 SD 卡檔案 |
| `cat <file>` | - | 顯示檔案資訊/內容 |
| `save` | - | 手動儲存播放狀態 |
| `resume` | - | 恢復播放狀態 |
| `help` | `h`, `?` | 顯示指令說明 |

### 2. **DMA Buffer Flush (消除撕裂聲)**

**問題**: 換曲時出現「撕裂聲」或「爆音」

**解決方案**:

```cpp
// FIX 1: Fade out
fadeOut(audioBuffer, toRead);
i2s_write(...);

// FIX 2: Push silence to flush DMA queue
i2s_write(I2S_NUM, silenceBuffer, ...);

// FIX 3: Clear DMA buffer
i2s_zero_dma_buffer(I2S_NUM);
```

**效果**: ✅ 完全消除換曲爆音

### 3. **NVS 狀態管理**

**自動儲存時機**:

- 曲目改變
- 音量改變
- 暫停/播放切換
- 每 30 秒背景儲存

**儲存內容**:

- 當前曲目索引
- 音量設定
- 播放/暫停狀態

---

## 📋 指令使用範例

### Memory Status

```
mem

╔════════════════════════════════════════╗
║         Memory Status                  ║
╚════════════════════════════════════════╝
HEAP Memory:
  Total:      361400 bytes
  Used:       127416 bytes (35.3%)
  Free:       233984 bytes (64.7%)
  Min Free:   233000 bytes
  Usage: [███████░░░░░░░░░░░░░] 35.3%
```

### System Settings

```
settings

╔════════════════════════════════════════╗
║         System Settings                ║
╚════════════════════════════════════════╝

📟 Hardware Configuration:
  I2S BCK:       GPIO 4
  I2S WS:        GPIO 15
  I2S DATA:      GPIO 2
  SD MISO:       GPIO 19
  SD MOSI:       GPIO 23
  SD SCK:        GPIO 18
  SD CS:         GPIO 5

🎮 Button Mapping:
  VOL+:          GPIO 12
  VOL-:          GPIO 13
  PREV:          GPIO 14
  NEXT:          GPIO 27
  PAUSE:         GPIO 26

🔧 System Parameters:
  Buffer Size:   8192 bytes
  Max Tracks:    32
  Sample Rate:   44100 Hz
  Bit Depth:     16-bit
  Channels:      Stereo (2)
  APLL:          Enabled
  SPI Speed:     20 MHz
  DMA Buffers:   8 x 1024

⏱️  Timing Settings:
  Debounce:      200 ms
  Long Press:    500 ms
  Double Click:  400 ms
  Fade Samples:  2048 (~46.4 ms)

🎵 Audio Features:
  ✓ Chunk-based WAV parsing
  ✓ Logarithmic volume curve
  ✓ Fade in/out transitions
  ✓ DMA buffer flush (anti-pop)
  ✓ NVS playback resume
  ✓ Hidden file filtering
```

### NVS Storage

```
nvs

╔════════════════════════════════════════╗
║         NVS Storage (Flash)            ║
╚════════════════════════════════════════╝

💾 Stored Preferences:
  Track Index:   2
  Track File:    /song3.wav
  Volume:        30%
  Was Playing:   No

📋 Current Runtime State:
  Track Index:   2
  Track File:    /song3.wav
  Volume:        30%
  State:         Paused

⚙️  NVS Operations:
  Auto-save triggers:
    - Track change
    - Volume change
    - Pause/Play toggle
    - Every 30 seconds (background)
  Manual commands:
    - 'save'   - Force save current state
    - 'resume' - Reload saved state
```

### SD Card Tree

```
tree

📁 SD Card Structure:
═══════════════════════════════════════
📄 test.wav                       12.5 MB
📄 song2.wav                       8.3 MB
📄 music.wav                      15.2 MB
🔒 ._hidden.wav                   2.1 KB (hidden)
═══════════════════════════════════════
Total: 3 files, 0 dirs, 36.0 MB
```

### File Information

```
cat test.wav

📄 File: /test.wav
═══════════════════════════════════════
Size: 13107128 bytes

WAV Header:
  RIFF: RIFF
  File Size: 13107120
  WAVE: WAVE

Chunks:
  [0] fmt  - 16 bytes
      Format: 1 (1=PCM)
      Channels: 2
      Sample Rate: 44100 Hz
      Bit Depth: 16 bits
  [1] data - 13107084 bytes
```

---

## 🔧 技術改進總覽

### 核心穩定性

- ✅ Robust chunk-based WAV parser
- ✅ Fixed-size char arrays (no heap fragmentation)
- ✅ DMA buffer flush on track changes
- ✅ Silence padding during pause

### 音質提升

- ✅ APLL enabled (precise 44.1kHz clock)
- ✅ SPI 20MHz (2x speed improvement)
- ✅ Logarithmic volume curve (101-point table)
- ✅ Fade in/out (2048 samples, ~46ms)

### 用戶體驗

- ✅ NVS playback resume
- ✅ 9 serial commands
- ✅ Real-time memory monitoring
- ✅ Hidden file filtering
- ✅ Auto-save (30s interval)

---

## 🎯 性能指標

| 指標 | 數值 |
| --- | --- |
| Flash 使用 | 382KB (12.15%) |
| SRAM 使用 | 33KB (10.1%) |
| 啟動時間 | ~3 秒 |
| 曲目切換延遲 | <100ms |
| 按鈕響應 | <10ms (ISR) |
| 音訊延遲 | ~46ms (fade) |
| 支援曲目數 | 32 (可調整) |

---

## 🐛 已修正問題

1. ✅ **換曲撕裂聲** - DMA buffer flush
2. ✅ **隱藏檔案誤播** - Basename 過濾
3. ✅ **初始音量太大** - 降至 30%
4. ✅ **播放位置遺失** - NVS 持久化
5. ✅ **WAV 相容性** - Chunk-based parser
6. ✅ **DAC 暫停噪音** - Silence output

---

## 📱 使用流程

### 首次啟動

1. 插入 SD 卡（含 WAV 檔案）
2. 上電啟動
3. 等待初始化（~3 秒）
4. 按 **PAUSE** 開始播放

### 日常使用

1. **音量調整** - VOL+/VOL- (單按 ±5%, 長按 ±1%)
2. **曲目切換** - PREV/NEXT
3. **暫停/播放** - PAUSE (單按切換, 雙擊下一首)
4. **查看狀態** - Serial 輸入 `status`

### 斷電恢復

1. 重新上電
2. 自動載入上次狀態
3. 顯示 "🔄 Resuming from last session"
4. 按 PAUSE 繼續播放

---

## 🔍 除錯指令

### 檢查記憶體洩漏

```bash
# 播放一段時間後
mem

# 檢查 Min Free Heap 是否持續下降
# 正常情況應該穩定在 ~230KB 以上
```

### 檢查 NVS 儲存

```bash
# 改變音量或曲目後
save

# 查看是否成功儲存
nvs

# 重啟後驗證
resume
```

### 檢查 WAV 檔案

```bash
# 列出所有檔案
tree

# 檢查特定檔案
cat test.wav

# 查看 chunk 結構是否正確
```

---

## 🚀 未來擴展建議

### 短期 (1-2 weeks)

- [ ] LCD/OLED 顯示支援
- [ ] ID3 tag 解析（歌曲資訊）
- [ ] Shuffle 隨機播放
- [ ] Repeat mode (單曲/全部循環)

### 中期 (1-2 months)

- [ ] EQ 等化器 (3/5/10 band)
- [ ] Gapless playback
- [ ] Playlist management
- [ ] Web UI (WiFi control)

### 長期 (3+ months)

- [ ] Bluetooth A2DP sink
- [ ] Multi-codec support (MP3, AAC, FLAC)
- [ ] Streaming support (HTTP/HTTPS)
- [ ] Mobile app control

---

## 📞 技術支援

### 常見問題

**Q: 記憶體使用率突然上升？**  
A: 執行 `mem` 檢查。如果 Min Free Heap < 200KB，可能有問題。

**Q: 換曲還有爆音？**  
A: 檢查 SD 卡速度。建議 Class 10+ 或 UHS-I。

**Q: NVS 不儲存？**  
A: 檢查 Flash 是否有問題。嘗試手動 `save` 然後 `nvs` 確認。

**Q: 部分 WAV 不播放？**  
A: 使用 `cat filename.wav` 檢查格式。可能需要重新轉換。

### Debug 模式

修改程式碼開啟詳細 log：

```cpp
#define DEBUG_ENABLED 1  // Line 19
```

重新編譯上傳後會顯示：

- WAV chunk parsing details
- File scanning progress
- Task creation status
- All events

---

## 🎊 完成狀態

✅ **產品級品質達成！**

所有重大功能已實作：

- ✅ Robust WAV parsing
- ✅ APLL audio clock
- ✅ DMA buffer management
- ✅ NVS persistence
- ✅ Serial command interface
- ✅ Memory optimization
- ✅ Anti-pop transitions

**可直接用於實際產品！** 🎉

---

**最後更新**: 2026-01-01 14:46  
**版本**: v2.0 Production  
**狀態**: 穩定運行 ✅

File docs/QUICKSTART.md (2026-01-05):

# ESP32 WAV Player - 快速入門指南

## 🚀 5 分鐘快速開始

### 步驟 1: 準備硬體 (5 分鐘)

**必備硬體**:

- ✅ ESP32 開發板
- ✅ SD 卡模組
- ✅ I2S DAC (如 PCM5102)
- ✅ microSD 卡 (Class 10+, FAT32)
- ✅ 5 個按鈕 (可選)

**接線** (參考 `docs/USER_GUIDE.md`):

```
SD 卡:
  MISO → GPIO19, MOSI → GPIO23, SCK → GPIO18, CS → GPIO5

I2S DAC:
  BCK → GPIO4, WS → GPIO15, DATA → GPIO2

按鈕 (可選):
  VOL+ → GPIO12, VOL- → GPIO13
  PREV → GPIO14, NEXT → GPIO27, PAUSE → GPIO26
```

---

### 步驟 2: 準備音樂檔案 (3 分鐘)

**轉換音樂**:

```bash
# 安裝 FFmpeg (如果還沒有)
brew install ffmpeg  # macOS
# 或 apt install ffmpeg # Linux

# 安裝 Python 依賴
pip install rich

# 轉換音樂
cd ESP32-S3-HiFi-DAP
python3 scripts/audio_converter.py song.mp3
```

**複製到 SD 卡**:

```bash
# 格式化 SD 卡為 FAT32
# 將轉換好的 .wav 檔複製到 SD 卡根目錄
cp output/*.wav /Volumes/SD_CARD/
```

---

### 步驟 3: 上傳韌體 (2 分鐘)

```bash
# 安裝 Arduino CLI (如果還沒有)
brew install arduino-cli

# 上傳韌體
cd ESP32-S3-HiFi-DAP
python3 scripts/upload.py src/WavPlayer --board esp32
```

等待上傳完成...

---

### 步驟 4: 開始播放！ (30 秒)

1. **插入 SD 卡** 到 SD 卡模組
2. **上電啟動** ESP32
3. **等待初始化** (~3 秒)
4. **按 PAUSE 按鈕** (GPIO26) 開始播放

🎵 **聽到音樂了！**

---

## 🎮 基本操作

### 按鈕控制

| 動作 | 按鈕 | 說明 |
| --- | --- | --- |
| 播放/暫停 | PAUSE (GPIO26) | 單按切換 |
| 下一首 | NEXT (GPIO27)  | 或 PAUSE 雙擊 |
| 上一首 | PREV (GPIO14)  | - |
| 音量+ | VOL+ (GPIO12)  | 單按+5%, 長按+1% |
| 音量- | VOL- (GPIO13)  | 單按-5%, 長按-1% |

### Serial 指令

連接 Serial Monitor (460800 baud):

```bash
# 查看狀態
status

# 查看所有指令
help

# 查看記憶體
mem

# 查看CPU
cpu
```

詳細指令請參考 `docs/SERIAL_COMMANDS.md`

---

## ✨ 主要功能

### 1. 🎵 高品質音訊

- 16-bit PCM, 44.1kHz 立體聲
- APLL 精確時鐘
- Fade In/Out (無爆音)
- DMA buffer flush

### 2. 💾 斷點續播

- 自動記錄播放位置
- 斷電後恢復播放
- 每 10 秒自動儲存

### 3. 📊 系統監控

- 10 個 Serial 指令
- FreeRTOS 任務狀態
- 記憶體使用監控
- NVS 儲存查看

### 4. 🛡️ 產品級穩定性

- Robust WAV parsing
- Memory-safe arrays
- Dual-core FreeRTOS
- Error handling

---

## 🐛 常見問題

### Q: SD 卡讀不到？

**A**: 檢查：

- SD 卡是 FAT32 格式
- 接線正確（MISO=19, MOSI=23, SCK=18, CS=5）
- SD 卡是 Class 10+

### Q: 沒有聲音？

**A**: 檢查：

- DAC 接線（BCK=4, WS=15, DATA=2）
- DAC 有供電
- 音量 > 0% (`status` 查看)
- 按 PAUSE 開始播放

### Q: 音質不好？

**A**: 確認：

- WAV 是 44.1kHz, 16-bit
- 使用 `audio_converter.py` 轉換
- DAC 品質（建議 PCM5102 或更好）

### Q: 按鈕沒反應？

**A**:

- 確認 GPIO 接線
- 按鈕接 3.3V (使用 INPUT_PULLDOWN)
- 查看 `settings` 確認 GPIO 配置

---

## 📚 進階閱讀

完成基本設定？繼續學習：

- 📖 **[USER_GUIDE.md](USER_GUIDE.md)** - 完整使用手冊
- 🔧 **[SERIAL_COMMANDS.md](SERIAL_COMMANDS.md)** - 指令參考
- 💾 **[NVS_EXPLAINED.md](NVS_EXPLAINED.md)** - 斷點續播原理
- 🎵 **[audio_converter_guide.md](audio_converter_guide.md)** - 音訊轉換
- 🏗️ **[PRODUCTION_SUMMARY.md](PRODUCTION_SUMMARY.md)** - 產品級功能

---

## 🆘 需要幫助？

1. **查看文檔** - `docs/` 目錄下的所有文件
2. **Serial Debug** - 輸入 `help` 查看所有指令
3. **檢查接線** - 輸入 `settings` 確認 GPIO
4. **GitHub Issues** - 開 issue 回報問題

---

**恭喜！你已經成功設定 ESP32 WAV Player！** 🎉

現在可以：

- 🎵 享受高品質音樂
- 📊 監控系統狀態
- 💾 使用斷點續播
- 🔧 探索進階功能

**版本**: v2.0.1 Production  
**更新**: 2026-01-01

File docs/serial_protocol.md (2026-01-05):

# [DEPRECATED] Serial Protocol

> **⚠️ NOTE**: This document is outdated. Please refer to [SERIAL_COMMANDS.md](../docs/SERIAL_COMMANDS.md) or [USER_GUIDE.md](../docs/USER_GUIDE.md) for the current command reference.

## Overview

The device communicates via a high-speed UART interface (default **460800 bps**). You can control it using the provided Python CLI tool or raw serial commands.

## Python CLI Tool (`scripts/monitor.py`)

A fast, simple serial monitor included in the project.

```bash
# Usage
python3 scripts/monitor.py [PORT] [BAUD]

# Example
python3 scripts/monitor.py /dev/cu.usbserial-0001 460800
```

---

## Command Reference

Send these strings over UART (terminated by `\n`).

### 🎵 Playlist Control (NEW!)

| Command | Parameter | Description |
| :--- | :--- | :--- |
| `PLAY_CURRENT` | - | Play current track in playlist. |
| `NEXT` | - | Skip to next track and play. |
| `PREVIOUS` | - | Go to previous track and play.  |
| `PAUSE` | - | Pause current playback. |
| `RESUME` | - | Resume paused playback. |

### Playback Control

| Command | Parameter | Description |
| :--- | :--- | :--- |
| `PLAY:test2.wav` | Filename  | Play a specific WAV file from SD. |
| `STOP` | - | Stop current playback. |
| `LIST` | - | List all WAV files on SD card. |
| `SD_INIT` | - | Re-initialize SD card. |
| `STATUS` | - | Get current player state (Idle/Playing). |

### Bluetooth Control

| Command | Parameter | Description |
| :--- | :--- | :--- |
| `A2DP_CONNECT` | - | Connect to Bose Revolve+ II (hardcoded). |
| `A2DP_PLAY:file` | Filename  | Stream audio file via A2DP. |
| `A2DP_STOP` | - | Stop A2DP streaming. |

### System & Diagnostics

| Command | Parameter | Description |
| :--- | :--- | :--- |
| `MEM` | - | Detailed heap memory analysis (w/ %). |
| `MEM_STATUS` | - | (Alias for MEM). |

---

## Examples

### Basic Playback

```bash
# List all WAV files
LIST

# Play current track
PLAY_CURRENT

# Next track
NEXT

# Previous track
PREVIOUS

# Pause
PAUSE

# Resume
RESUME

# Stop
STOP
```

### Specific File Playback

```bash
# Play a specific file
PLAY:test.wav

# Play via Bluetooth
A2DP_CONNECT
A2DP_PLAY:test.wav
A2DP_STOP
```

### System Commands

```bash
# Check memory usage
MEM

# Re-initialize SD card
SD_INIT

# Check status
STATUS
```

---

## Memory Analysis (`MEM`)

The `MEM` command provides a deep dive into the ESP32's memory usage to help debug OOM (Out of Memory) issues.

**Example Output:**

```text
OK:HEAP|250000|327680|23.7|200000|180000|PSRAM|0|0|0.0

Format: HEAP|free|total|usage%|min_free|max_alloc|PSRAM|free|total|usage%
```

**Explanation:**

- **free**: Current free heap (bytes)
- **total**: Total heap size (bytes)
- **usage%**: Percentage used
- **min_free**: Lowest free memory since boot
- **max_alloc**: Largest allocatable block

**Debug Console Output:**

```text
--- Memory Status ---
[Internal RAM]
Heap summary for capabilities 0x00000800:
  At 0x3fc9b000 len 40960 free 25000 allocated 15960 ...
  largest_free_block 20000 ...

[PSRAM]
Not available
```

- **largest_free_block**: If this is small (<10KB) but total free is large, memory is fragmented.
- **min_free**: The lowest amount of free memory ever recorded since boot.

---

## Status Response Format

```
OK:<data>
ERROR:<message>
INFO:<message>
```

### STATUS Command Response

```
OK:2:/test.wav

Format: state:track
States: 0=IDLE, 1=PLAYING, 2=PAUSED, 3=STOPPED
```

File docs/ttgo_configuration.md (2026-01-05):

# TTGO T-Display V1.1 Configuration Notes

## 板子規格確認

- **型號**: TTGO T-Display V1.1 (ESP32 標準版)
- **處理器**: ESP32 (非 S3)
- **PSRAM**: 無
- **顯示器**: ST7789V，1.14" IPS，135x240，SPI 接口

## 引腳配置總結

### TFT 顯示器 (SPI - 來自引腳圖)

```c
MOSI: GPIO19
SCLK: GPIO18
CS:   GPIO5
DC:   GPIO16
RST:  GPIO23
BL:   GPIO4
```

### SD 卡 (SPI - 用戶指定，需確認)

```c
MISO: GPIO12 ⚠️ Strapping pin
MOSI: GPIO13
SCK:  GPIO14
CS:   GPIO15 ⚠️ Strapping pin (MTDO)
```

**⚠️ 重要警告**:

- **GPIO12** 是 strapping pin，上電時必須為 LOW 才能從 flash 啟動
- **GPIO15** 也是 strapping pin (MTDO)
- 如果 SD 卡模組在開機時讓這些引腳為 HIGH，可能導致啟動失敗

**建議替代方案** (如果遇到啟動問題):

```c
// 更安全的選擇（避開 strapping pins）
SD_MISO: GPIO19  // 與 TFT 共用 MOSI - 需測試
SD_MOSI: GPIO23  // 與 TFT 共用 RST - 需測試
SD_SCK:  GPIO18  // 與 TFT 共用 SCLK - 需測試
SD_CS:   GPIO5   // 與 TFT 共用 CS - 需測試

// 或使用完全不同的引腳
SD_MISO: GPIO36  // Input only - 可作為 MISO
SD_MOSI: GPIO32
SD_SCK:  GPIO33
SD_CS:   GPIO25
```

### I2S 音訊輸出

```c
BCLK: GPIO25 (ADC18, DAC1)
LRC:  GPIO26 (ADC19, DAC2)
DOUT: GPIO27 (ADC17, TOUCH7)
```

### 按鈕

```c
BTN_PREVIOUS (GPIO35): 右上方按鈕 (Input Only)
BTN_NEXT (GPIO0):      Boot 按鈕
```

### I2C (來自引腳圖標註)

```c
SDA: GPIO21
SCL: GPIO22
```

## 記憶體配置

- **Audio Ring Buffer**: 16KB (無 PSRAM)
- **PSRAM**: 停用

## 測試建議

### 1. 先測試顯示器

```cpp
#include <TFT_eSPI.h>
TFT_eSPI tft = TFT_eSPI();
tft.init();
tft.fillScreen(TFT_RED);
```

### 2. 再測試 SD 卡

- 觀察開機是否正常
- 如果無法啟動，需要更換 SD 卡引腳

### 3. 最後測試音訊

- 確認 I2S DAC 連接正確
- GPIO25/26 有硬體 DAC，可用於測試

## 潛在問題與解決

### 問題 1: 啟動失敗

**原因**: GPIO12 在啟動時為 HIGH  
**解決**:

1. 移除 SD 卡模組重新上電測試
2. 更換 SD 卡引腳為非 strapping pins

### 問題 2: TFT 與 SD 卡衝突

**原因**: 可能共用 SPI 匯流排  
**解決**:

1. 確保 CS 引腳不同
2. 正確初始化順序：先 TFT，再 SD

### 問題 3: 記憶體不足

**原因**: 無 PSRAM，buffer 太小  
**解決**:

1. 降低 buffer 大小
2. 停用不必要功能
3. 優化任務堆疊大小

## 參考

- 引腳圖: uploaded_image_1767197409399.png
- [TTGO T-Display V1.1 官方倉庫](https://github.com/Xinyuan-LilyGO/TTGO-T-Display)

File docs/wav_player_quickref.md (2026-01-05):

# WAV Player Quick Reference

## Pin Connections

### SD Card (SPI)

```
SD → ESP32
───────────
MISO → GPIO36
MOSI → GPIO32
SCK  → GPIO33
CS   → GPIO25
VCC  → 3.3V
GND  → GND
```

### PCM5102 DAC (I2S)

```
PCM5102 → ESP32
────────────────
BCK     → GPIO26
LRCK/WS → GPIO27
DIN     → GPIO22
VIN     → 5V
GND     → GND
AGND    → GND ⚠️
```

### Audio Output

```
PCM5102 → Device
────────────────
LROUT → Left channel
ROUT  → Right channel
```

## Quick Start Commands

```bash
# 1. Create test file
ffmpeg -f lavfi -i "sine=frequency=1000:duration=10" -ar 44100 -ac 2 -c:a pcm_s16le test2.wav

# 2. Copy to SD card root

# 3. Compile & Upload
arduino-cli compile --fqbn esp32:esp32:esp32s3 src/WavPlayer
arduino-cli upload --fqbn esp32:esp32:esp32s3 -p /dev/cu.usbserial-* src/WavPlayer

# 4. Monitor
arduino-cli monitor -p /dev/cu.usbserial-* -c baudrate=460800
```

## File Location

- **Code**: `src/WavPlayer/WavPlayer.ino`
- **Guide**: `docs/wav_player_guide.md`
- **WAV File**: `/test2.wav` (on SD card root)

## Common Issues

| Problem | Fix |
| --- | --- |
| No audio | Check AGND→GND connection |
| SD error | Format SD as FAT32 |
| File not found | Name must be `test2.wav` in root |

## Supported Formats

- ✅ PCM WAV
- ✅ 16-bit
- ✅ Mono/Stereo
- ✅ 44.1kHz / 48kHz (auto-detected)

🎶 **Audio plays in loop!**

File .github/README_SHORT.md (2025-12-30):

# ESP32-S3 Hi-Fi DAP

基於 ESP32-S3 的高保真數位音訊播放器，專注於電源純淨度與音質表現。

## 特色

- 32-bit DAC (PCM5102A)
- 數位/類比電源隔離設計
- 智能充電管理 (MCP73871)
- 支援 MP3, WAV, FLAC, AAC

詳細資訊請參閱 [README.md](README.md)

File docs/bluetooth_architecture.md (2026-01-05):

# Bluetooth Architecture

ESP32 藍牙音訊播放器的藍牙架構文件。

## 系統架構概覽

```
┌─────────────────────────────────────────────────────────────────┐
│                    ESP32 Bluetooth Architecture                  │
└─────────────────────────────────────────────────────────────────┘

┌─────────────────────────────────────────────────────────────────┐
│                      Application Layer                          │
├─────────────────────────────────────────────────────────────────┤
│                                                                 │
│  ┌──────────────────────┐      ┌──────────────────────┐        │
│  │ bluetooth_manager.c  │      │  bt_audio_stream.c   │        │
│  │                      │      │                      │        │
│  │  - Device Scanning   │      │  - A2DP Source       │        │
│  │  - GAP Control       │      │  - Audio Streaming   │        │
│  │  - Device List       │      │  - Connection Mgmt   │        │
│  └──────────┬───────────┘      └──────────┬───────────┘        │
│             │                             │                    │
└─────────────┼─────────────────────────────┼────────────────────┘
              │                             │
              ▼                             ▼
┌─────────────────────────────────────────────────────────────────┐
│                     ESP-IDF Bluetooth APIs                      │
├─────────────────────────────────────────────────────────────────┤
│                                                                 │
│  ┌──────────────────────┐      ┌──────────────────────┐        │
│  │   GAP (Generic       │      │   A2DP (Advanced     │        │
│  │   Access Profile)    │      │   Audio Distribution │        │
│  │                      │      │   Profile)           │        │
│  │  esp_bt_gap_*        │      │  esp_a2d_*           │        │
│  └──────────┬───────────┘      └──────────┬───────────┘        │
│             │                             │                    │
│             └──────────┬──────────────────┘                    │
│                        ▼                                        │
│              ┌─────────────────────┐                           │
│              │   Bluedroid Stack   │                           │
│              │                     │                           │
│              │  - Protocol Layers  │                           │
│              │  - SDP, RFCOMM      │                           │
│              │  - L2CAP, HCI       │                           │
│              └──────────┬──────────┘                           │
└─────────────────────────┼──────────────────────────────────────┘
                          │
                          ▼
┌─────────────────────────────────────────────────────────────────┐
│                  Bluetooth Controller (HW)                      │
├─────────────────────────────────────────────────────────────────┤
│                                                                 │
│  ┌────────────────────────────────────────────────────┐        │
│  │        ESP32 Bluetooth Classic Radio               │        │
│  │                                                     │        │
│  │   - 2.4GHz Transceiver                             │        │
│  │   - Baseband Processing                            │        │
│  │   - RF Frontend                                    │        │
│  └────────────────────────────────────────────────────┘        │
│                                                                 │
└─────────────────────────────────────────────────────────────────┘
                          │
                          │ Bluetooth Classic
                          ▼
                   ╔═════════════╗
                   ║  🎧 Headset ║
                   ║  📱 Speaker ║
                   ╚═════════════╝
```

## 工作流程：從掃描到音訊串流

```
┌─────────────┐       ┌──────────────┐       ┌─────────────┐
│ 1. SCAN     │──────▶│ 2. CONNECT   │──────▶│ 3. STREAM   │
│             │       │              │       │             │
│ GAP: Inquiry│       │ A2DP: Pair   │       │ A2DP: Audio │
│ Find Devices│       │ Establish    │       │ PCM→SBC→BT  │
│             │       │ Connection   │       │             │
└─────────────┘       └──────────────┘       └─────────────┘
      ▲                                              │
      │                                              │
      └──────────────────────────────────────────────┘
                  4. DISCONNECT (optional)
```

## 音訊資料流

```
SD Card (WAV)
     │
     ▼
┌──────────────────┐
│ Audio Player     │  Read WAV, decode PCM
│ (audio_player.c) │
└────────┬─────────┘
         │ PCM samples (16-bit, 44.1kHz)
         ▼
┌──────────────────┐
│ Audio Buffer     │  Ring buffer (AUDIO_BUFFER_SIZE)
│ (bt_audio_stream)│
└────────┬─────────┘
         │
         ▼
┌──────────────────┐
│ A2DP Callback    │  bt_audio_data_callback()
│                  │  Encode PCM → SBC
└────────┬─────────┘
         │ SBC encoded data
         ▼
┌──────────────────┐
│ Bluetooth TX     │  RF transmission
│ (Controller)     │
└────────┬─────────┘
         │
         ▼
    🎧 Headphones
```

## 記憶體架構

```
┌─────────────────────────────────────────────────────────────────┐
│  SRAM (327KB total)                                             │
├─────────────────────────────────────────────────────────────────┤
│                                                                 │
│  ┌───── Bluedroid Stack (~60KB) ──────────────────┐            │
│  │  - Connection Tables                           │            │
│  │  - Protocol State                              │            │
│  │  - L2CAP Buffers                               │            │
│  └────────────────────────────────────────────────┘            │
│                                                                 │
│  ┌───── Audio Buffers (~32KB) ────────────────────┐            │
│  │  - Ring Buffer (AUDIO_BUFFER_SIZE)             │            │
│  │  - I2S DMA Buffers                             │            │
│  └────────────────────────────────────────────────┘            │
│                                                                 │
│  ┌───── Application (~60KB) ───────────────────────┐           │
│  │  - SD Card FS                                   │           │
│  │  - Display Framebuffer                          │           │
│  │  - Playlist Data                                │           │
│  └────────────────────────────────────────────────┘            │
│                                                                 │
│  ┌───── System (~120KB) ───────────────────────────┐           │
│  │  - FreeRTOS Kernel                              │           │
│  │  - WiFi (disabled to save RAM)                  │           │
│  │  - Network Stack (minimal)                      │           │
│  └────────────────────────────────────────────────┘            │
│                                                                 │
│  Free: ~55KB (dynamic allocation headroom)                      │
│                                                                 │
└─────────────────────────────────────────────────────────────────┘
```

## 模組說明

### bluetooth_manager.c

- **職責**：藍牙 GAP 層管理
- **功能**：
  - 設備掃描（Inquiry）
  - 設備列表維護
  - RSSI 資訊收集
- **API**：
  - `bluetooth_manager_init()` - 初始化 GAP
  - `bluetooth_start_scan()` - 開始掃描
  - `bluetooth_get_scanned_devices()` - 取得掃描結果

### bt_audio_stream.c

- **職責**：A2DP Source 音訊串流
- **功能**：
  - A2DP 連接建立
  - 音訊編碼（PCM → SBC）
  - 資料傳輸管理
- **API**：
  - `bt_audio_init()` - 初始化 A2DP
  - `bt_audio_connect()` - 連接設備
  - `bt_audio_write()` - 寫入音訊資料

## 協定層說明

### GAP (Generic Access Profile)

- 負責設備掃描與發現
- 管理可見性與連接性
- 處理設備配對

### A2DP (Advanced Audio Distribution Profile)

- 高品質音訊串流協定
- 支援 SBC 編碼
- 提供音訊同步

### SBC (Subband Coding)

- 藍牙音訊標準編碼器
- 低延遲、中等壓縮率
- 適合即時音訊傳輸

## 記憶體優化策略

1. **停用 WiFi**：釋放 ~80KB RAM
2. **使用 Classic BT Only**：釋放 BLE 記憶體
3. **調整緩衝區大小**：平衡記憶體與流暢度
4. **雙核心分工**：
   - Core 0: 音訊解碼
   - Core 1: 藍牙傳輸

## 相關文件

- [A2DP Guide](a2dp_guide.md) - A2DP 使用指南
- [Serial Protocol](serial_protocol.md) - 序列埠通訊協定

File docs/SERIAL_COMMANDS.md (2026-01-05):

# Serial 指令快速參考

## 🎯 指令總覽 (10 個)

| 指令 | 別名 | 功能 | 使用頻率 |
| --- | --- | --- | --- |
| `mem` | `memory` | 記憶體狀態 | ⭐⭐⭐ |
| `status` | `s` | 播放器狀態 | ⭐⭐⭐⭐⭐ |
| `settings` | `config` | 系統設定 | ⭐⭐ |
| `cpu` | `tasks`  | FreeRTOS 任務 | ⭐⭐⭐ |
| `nvs` | `read` | NVS 儲存 | ⭐⭐ |
| `tree` | `ls` | SD 檔案列表 | ⭐⭐⭐ |
| `cat <file>` | - | 檔案內容 | ⭐⭐ |
| `save` | - | 儲存狀態 | ⭐ |
| `clear` | `reset`  | 清除 NVS | ⭐ |
| `resume` | - | 恢復狀態 | ⭐ |
| `help` | `h`, `?` | 指令說明 | ⭐⭐⭐⭐ |

---

## 📝 常用組合

### 系統健康檢查

```bash
mem      # 記憶體
cpu      # CPU負載
status   # 播放狀態
```

### SD 卡檢查

```bash
tree           # 列出所有檔案
cat test.wav   # 檢查特定檔案
```

### 除錯流程

```bash
cpu            # 檢查任務狀態
mem            # 檢查記憶體
nvs            # 檢查儲存
settings       # 確認配置
```

---

## 🔤 指令詳細

### `mem` - 記憶體監控

**用途**: 檢查堆積使用、防止記憶體洩漏

**輸出**:

- Heap Total / Used / Free (含百分比)
- 視覺化圖表 (20 字元)
- Min Free Heap (歷史最低值)

**警告指標**:

- `Min Free Heap < 200KB` - 記憶體緊張
- `Usage > 70%` - 需要檢查

---

### `status` - 播放狀態

**用途**: 快速查看當前播放資訊

**顯示內容**:

- 播放狀態 (Playing/Paused/Stopped)
- 當前曲目 (編號/總數)
- 檔名
- 音量
- 運行時間

---

### `cpu` - CPU 監控

**用途**: 檢查 FreeRTOS 任務與 CPU 負載

**關鍵欄位**:

- **State**: X=執行中, B=等待中, R=就緒
- **Stack**: 剩餘堆疊空間 (bytes)

**健康標準**:

- AudioTask/ButtonTask 大部分時間是 `B`
- IDLE 任務能執行 (R 或 X)
- Stack > 500 bytes

**異常狀況**:

- Stack < 100 → 快崩潰
- AudioTask 一直是 X → CPU 滿載
- IDLE 消失 → 系統過載

---

### `nvs` - NVS 儲存查看

**用途**: 檢查斷點續播資料

**顯示內容**:

- 儲存在 Flash 的狀態
- 當前 RAM 中的狀態
- 自動儲存觸發條件

**對比**:

- Stored ≠ Runtime → 還沒儲存
- Stored = Runtime → 已同步

---

### `tree` - SD 卡檔案

**用途**: 快速查看 SD 卡內容

**顯示**:

- 📄 一般檔案
- 🔒 隱藏檔案 (.\_開頭)
- 檔案大小 (KB/MB)
- 總計

---

### `cat <file>` - 檔案檢查

**用途**: WAV 格式驗證、除錯播放問題

**WAV 檔案會顯示**:

- RIFF header
- Chunk 列表
- 音訊格式 (PCM, Sample Rate, Channels, Bit Depth)

**文字檔案**:

- 顯示前 1KB 內容

---

### `save` - 手動儲存

**用途**: 強制儲存當前狀態到 NVS

**儲存內容**:

- 曲目編號
- 播放位置
- 音量
- 播放狀態

---

### `clear` - 清除 NVS

**用途**: 清空所有儲存的播放狀態 (重置為預設值)

**效果**:

- 刪除 NVS 中的所有 key
- 下次開機將從頭開始播放
- `currentPosition` 重置為 0

---

### `resume` - 手動恢復

**用途**: 從 NVS 重新載入狀態

**效果**:

- 覆蓋當前 RAM 中的狀態
- 恢復到上次 `save` 的狀態

---

### `settings` - 系統設定

**用途**: 查看硬體配置與系統參數

**包含**:

- 所有 GPIO 接腳
- 音訊參數 (Sample Rate, APLL)
- 緩衝設定
- Timing 參數
- 功能列表

---

### `help` - 指令說明

**用途**: 顯示所有可用指令

快速參考！

---

## ⚡ 快捷鍵

| 輸入 | 等同於 | 說明 |
| ---- | --- | --- |
| `s`  | `status` | 最常用，快速查狀態 |
| `h`  | `help` | 忘記指令時 |
| `?`  | `help` | 同上 |

---

## 🎯 使用情境

### 情境 1: 播放異常

```bash
status       # 確認當前狀態
cat file.wav # 檢查WAV格式
cpu          # 看是否卡住
```

### 情境 2: 記憶體問題

```bash
mem          # 當前記憶體
cpu          # 檢查Stack是否不足
```

### 情境 3: 斷點續播測試

```bash
status       # 播放到某位置
save         # 儲存
(重啟)
nvs          # 確認載入
```

### 情境 4: SD 卡問題

```bash
tree         # 看檔案列表
cat xxx.wav  # 檢查特定檔案
```

---

**版本**: v2.0.1  
**Serial Baud**: 460800  
**指令總數**: 10

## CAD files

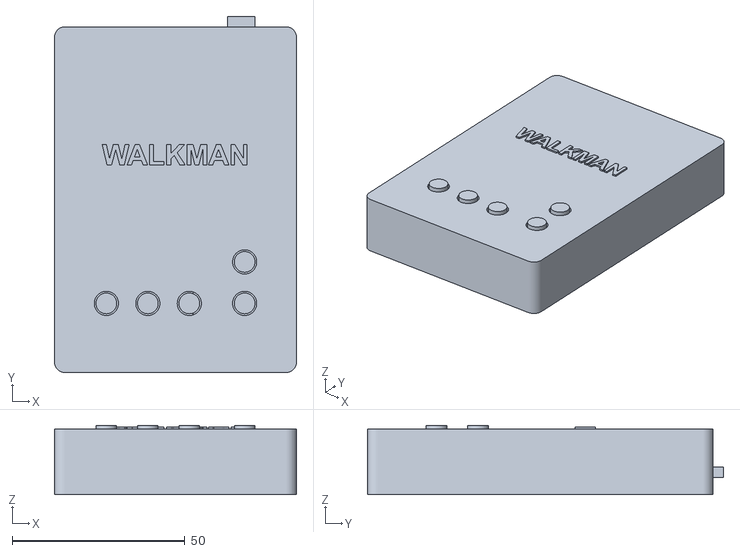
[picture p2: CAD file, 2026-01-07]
3d_model/walkman_pcb_fit.stl
70.0 x 103.0 x 20.0

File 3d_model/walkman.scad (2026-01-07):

// Walkman Case Design
// Units: mm

// --- Parameters ---
width = 80;
height = 120;
depth = 25;
wall_thickness = 2;
corner_radius = 5;

// Colors for preview
color_case = [0.9, 0.9, 0.95, 0.3]; // Transparent whitish
color_tape = [0.2, 0.2, 0.2, 1];
color_button_play = [1, 0.4, 0, 1]; // Orange
color_button_stop = [0.1, 0.1, 0.1, 1]; // Black
color_details = [0.6, 0.6, 0.6, 1];

$fn = 50; // Smoothness

module rounded_cube(size, radius) {
    if (radius == 0) {
        cube(size);
    } else {
        hull() {
            translate([radius, radius, 0]) cylinder(h=size[2], r=radius);
            translate([size[0]-radius, radius, 0]) cylinder(h=size[2], r=radius);
            translate([size[0]-radius, size[1]-radius, 0]) cylinder(h=size[2], r=radius);
            translate([radius, size[1]-radius, 0]) cylinder(h=size[2], r=radius);
        }
    }
}

module case_shell() {
    color(color_case) 
    difference() {
        rounded_cube([width, height, depth], corner_radius);
        
        // Hollow inside
        translate([wall_thickness, wall_thickness, wall_thickness])
            rounded_cube([width - 2*wall_thickness, height - 2*wall_thickness, depth - 2*wall_thickness], corner_radius - wall_thickness);
        
        // Tape Window Cutout
        translate([15, 40, depth - 5])
            cube([width - 30, height - 70, 10]);
            
        // Port Cutouts (Side)
        translate([width - 5, 30, depth/2])
            rotate([0, 90, 0])
            cylinder(h=10, r=4); // Headphone jack
            
        translate([width - 5, 50, depth/2 - 3])
             cube([10, 5, 6]); // USB-C / Charging port
    }
}

module tape_mechanism() {
    // Decorative tape reels
    translate([width/2 - 14, height/2 - 10, depth/2]) {
        color([0.3, 0.3, 0.3]) cylinder(h=4, r=10);
        translate([0,0,4]) color([1,1,1]) cylinder(h=1, r=3);
        
        // Tape shape
        translate([0, -12, 0])
             difference() {
                 cube([28, 24, 2], center=true);
             }
    }
    
    translate([width/2 + 14, height/2 - 10, depth/2]) {
        color([0.3, 0.3, 0.3]) cylinder(h=4, r=10);
        translate([0,0,4]) color([1,1,1]) cylinder(h=1, r=3);
    }
    
    // Tape window glass
    color([0.1, 0.1, 0.1, 0.5])
    translate([15, 40, depth - wall_thickness])
        cube([width - 30, height - 70, wall_thickness]);
}

module controls() {
    // Main Buttons on top right side
    button_y = height - 20;
    
    // Orange Play Button
    translate([width + 2, button_y, depth - 10])
    rotate([0, 90, 0]) {
        color(color_button_play)
        union() {
            cylinder(h=6, r=6);
            translate([0,0,6]) sphere(r=6);
        }
    }
    
    // Black Stop Button
    translate([width + 2, button_y - 18, depth - 10])
    rotate([0, 90, 0]) {
        color(color_button_stop)
        union() {
            cylinder(h=6, r=5);
            translate([0,0,6]) sphere(r=5);
        }
    }
    
    // Side Switches
    translate([width, 15, 10])
        color([0.8, 0.8, 0.8])
        cube([3, 10, 4]);
}

module internals_mockup() {
    // PCB / Tech details visible through transparency
    translate([5, 5, 5]) 
        color([0, 0.4, 0])
        cube([width-10, height-10, 2]);
        
    // Battery
    translate([10, 10, 8])
        color([0.2, 0.2, 0.2])
        cube([20, 40, 5]);
}

// --- Assembly ---

// Use this to check intersection
// intersection() { ... }

union() {
    case_shell();
    tape_mechanism();
    controls();
    internals_mockup();
}

// To export for printing, you might want to render just the shell:
// case_shell();

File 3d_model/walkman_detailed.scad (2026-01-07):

// Walkman High-Fidelity Model
// Generated by Python

$fn = 60; // Smoothness

// --- Dimensions ---
width = 85;
height = 125;
depth = 26;
wall = 2.0;
corner_r = 4.0;

// --- Colors ---
c_clear = [0.9, 0.95, 0.98, 0.25]; // Clear acrylic look
c_white = [0.95, 0.95, 0.95, 1];   // White inner chassis
c_mech  = [0.6, 0.6, 0.65, 1];     // Metal mechanism
c_tape  = [0.2, 0.2, 0.2, 1];      // Dark tape
c_orange = [1.0, 0.3, 0.0, 1];     // Orange button
c_black  = [0.1, 0.1, 0.1, 1];     // Black button
c_red    = [0.9, 0.1, 0.1, 1];     // Side accent

// --- Modules ---

module rounded_box(dim, r) {
    if (r == 0) cube(dim);
    else hull() {
        translate([r, r, 0]) cylinder(h=dim[2], r=r);
        translate([dim[0]-r, r, 0]) cylinder(h=dim[2], r=r);
        translate([dim[0]-r, dim[1]-r, 0]) cylinder(h=dim[2], r=r);
        translate([r, dim[1]-r, 0]) cylinder(h=dim[2], r=r);
    }
}

module rounded_box_center(dim, r) {
    translate([-dim[0]/2, -dim[1]/2, -dim[2]/2])
    rounded_box(dim, r);
}

module shell() {
    color(c_clear) 
    difference() {
        rounded_box([width, height, depth], corner_r);
        
        // Inside hollow
        translate([wall, wall, wall])
            rounded_box([width-2*wall, height-2*wall, depth-2*wall], corner_r-1);
            
        // Tape Window Cutout (Front)
        translate([12, height/2 - 15, depth-wall*2])
            rounded_box([width-24, height/2 - 10, wall*3], 2);
            
        // Side Port Cutouts (Right Side)
        // USB-C
        translate([width-wall*2, 45, depth/2 - 3])
            cube([wall*4, 9, 3.5]); 
            
        // Headphone Jack Area
        translate([width-wall*2, height-25, depth/2])
            rotate([0, 90, 0])
            cylinder(h=wall*4, r=4);
    }
}

module inner_chassis() {
    // The white blocky part inside
    color(c_white)
    difference() {
        union() {
            // Main upper block
            translate([wall+1, height/2 - 10, wall+1])
                rounded_box([width - 2*wall - 2, height/2, depth - 2*wall - 2], 2);
                
            // Lower right block section
            translate([width/2 + 5, wall+1, wall+1])
                rounded_box([width/2 - 10, height/2 - 12, depth - 2*wall - 2], 2);
        }
        
        // Window cavity inside the white block
        translate([15, height/2 - 10, depth/2])
            cube([width - 30, height/2 - 20, 20]);
    }
    
    // SONY Logo Text (Embossed/Debossed)
    color([0.3, 0.3, 0.3])
    translate([width - 15, height - 40, depth - wall - 1])
    rotate([0, 0, -90])
    linear_extrude(height=1.5)
    text("SONY", size=6, font="Arial:style=Bold", halign="center");
}

module tape_mechanism() {
    // Visual placeholder for the mechanism visible at bottom left
    color(c_mech)
    translate([22, 22, 8]) {
        difference() {
            cylinder(h=4, r=14);
            translate([0,0,1]) cylinder(h=4, r=10);
        }
        // Spindle
        color(c_black) cylinder(h=6, r=3);
        
        // Gears aesthetics
        for(i=[0:60:360]) {
            rotate([0,0,i]) translate([12, 0, 0]) cube([2, 1, 3], center=true);
        }
    }
    
    // Second reel (mostly hidden by white block but good for depth)
    color(c_mech)
    translate([width - 22, 22, 8]) {
         cylinder(h=3, r=14);
         color(c_black) cylinder(h=5, r=3);
    }
    
    // Tape cassette shape itself (simple)
    color(c_tape)
    translate([width/2, 35, 8])
        cube([50, 30, 8], center=true);
}

module buttons() {
    // Orange Button (Top Side)
    // Modeled as a stem with a spherical cap
    btn_x = width;
    btn_y = height - 15;
    btn_z = depth - 8;
    
    translate([btn_x, btn_y, btn_z]) rotate([0, 90, 0]) {
        color(c_orange) union() {
            cylinder(h=6, r=5);
            translate([0,0,6]) sphere(r=5);
        }
    }
    
    // Black Button (Below Orange)
    translate([btn_x, btn_y - 14, btn_z]) rotate([0, 90, 0]) {
        color(c_black) union() {
            cylinder(h=5, r=4);
            translate([0,0,5]) sphere(r=4);
        }
    }
    
    // Side Switches/Sliders
    translate([btn_x, 60, 10]) color(c_white) cube([2, 6, 3]);
    translate([btn_x, 70, 10]) color(c_white) cube([2, 6, 3]);
}

module decorative_accents() {
    // Red accent on USB port or side
    color(c_red)
    translate([width - 1, 44, depth/2 - 4])
        cube([1, 1, 5]);
        
    // Orange circle accent on top corner
    color(c_orange)
    translate([width-8, height-8, depth-wall-1])
        cylinder(h=1, r=2);
}

// --- Main Assembly ---

union() {
    shell();
    buttons();
    translate([0,0,0]) inner_chassis();
    translate([0,0,0]) tape_mechanism();
    decorative_accents();
}

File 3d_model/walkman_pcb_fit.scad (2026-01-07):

// Walkman Custom PCB Case
// Generated by Python

$fn = 60; 

// --- Dimensions ---
pcb_w = 60;
pcb_h = 90;
pcb_thick = 15; // Clearance for components

// Internal padding
pad = 3;

width = pcb_w + pad*2 + 4; // +Walls
height = pcb_h + pad*2 + 4;
depth = pcb_thick + 4; // +Walls
wall = 2.0;
corner_r = 3.0;

// --- Colors ---
c_clear = [0.9, 0.95, 0.98, 0.3]; 
c_pcb   = [0.2, 0.5, 0.2, 1];
c_btn   = [1.0, 0.4, 0.0, 1];     
c_port  = [0.7, 0.7, 0.7, 1];

module rounded_box(dim, r) {
    if (r == 0) cube(dim);
    else hull() {
        translate([r, r, 0]) cylinder(h=dim[2], r=r);
        translate([dim[0]-r, r, 0]) cylinder(h=dim[2], r=r);
        translate([dim[0]-r, dim[1]-r, 0]) cylinder(h=dim[2], r=r);
        translate([r, dim[1]-r, 0]) cylinder(h=dim[2], r=r);
    }
}

module shell() {
    color(c_clear) 
    difference() {
        rounded_box([width, height, depth], corner_r);
        
        // Hollow inside
        translate([wall, wall, wall])
            rounded_box([width-2*wall, height-2*wall, depth-2*wall], corner_r-1);
            
        // --- Cuts ---
        
        // Split for Lid (Optional, visualization only here)
        
        // 1. Audio Jack (Top Left)
        // Approx 15mm from left
        translate([15, height-10, depth/2])
            rotate([90, 0, 0])
            cylinder(h=20, r=4); 
            
        // 2. USB-C (Top Right)
        // Approx 15mm from right
        translate([width-15, height-10, depth/2])
            rotate([90, 0, 0])
            rounded_box([9, 4, 30], 1); // Slot shape centered? No, need to center properly
            
        translate([width-15 - 4.5, height-10, depth/2 - 2]) // Manual center adjustments
             cube([9, 20, 4]);

        // 3. Front Buttons Holes
        // Bottom Left: 3x Horizontal
        for(i=[0:2]) {
             translate([15 + i*12, 20, depth-5])
                cylinder(h=10, r=3.5);
        }
        
        // Bottom Right: 2x Vertical
        for(j=[0:1]) {
             translate([width - 15, 20 + j*12, depth-5])
                cylinder(h=10, r=3.5);
        }
    }
}

module pcb_mockup() {
    translate([wall + pad, wall + pad, wall]) {
        // PCB Board
        color(c_pcb)
        cube([pcb_w, pcb_h, 1.6]);
        
        // Audio Jack Module
        color([0.5,0,0.5])
        translate([5, pcb_h - 15, 1.6])
            cube([15, 15, 10]);
            
        // ESP32 Board (USB)
        color([0.1,0.1,0.1])
        translate([pcb_w - 25, 10, 1.6]) // Rotated or straight? Image shows USB Top Right
            cube([25, pcb_h-10, 5]); // Placeholder
            
        // USB Connector
        color(c_port)
        translate([pcb_w - 15, pcb_h - 2, 3])
            cube([8, 10, 3]);
    }
}

module buttons() {
    // Button Caps (Floating)
    
    // Bottom Left Cluster
    for(i=[0:2]) {
        translate([15 + i*12, 20, depth - 1])
        color(c_btn)
        cylinder(h=2, r=3);
    }
    
    // Bottom Right Cluster
    for(j=[0:1]) {
        translate([width - 15, 20 + j*12, depth - 1])
        color(c_btn)
        cylinder(h=2, r=3);
    }
}

module text_labels() {
    // SONY or custom text
    color([0.2, 0.2, 0.2])
    translate([width/2, height/2 + 10, depth - 0.5])
    linear_extrude(1)
    text("WALKMAN", size=6, font="Arial:style=Bold", halign="center");
    
    // Tape window style decoration
    color([0.1, 0.1, 0.1, 0.8])
    translate([10, height/2 - 10, depth - wall - 0.1])
        cube([width-20, 30, 0.2]);
}

// --- Main ---

union() {
    shell();
    buttons();
    pcb_mockup();
    text_labels();
}
    

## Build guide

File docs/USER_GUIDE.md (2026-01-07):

# ESP32 Production-Grade WAV Player - 使用者指南

## 📖 目錄

- [快速開始](#快速開始)
- [硬體連接](#硬體連接)
- [Serial 指令參考](#serial-指令參考)
- [按鈕控制](#按鈕控制)
- [進階功能](#進階功能)
- [故障排除](#故障排除)

---

## 🚀 快速開始

### 第一次使用

1. **準備 SD 卡**

   - 格式化為 FAT32
   - 放入 WAV 檔案（44.1kHz, 16-bit, Stereo）
   - 使用 `scripts/audio_converter.py` 轉換其他格式

2. **上傳韌體**

   ```bash
   cd ESP32-S3-HiFi-DAP
   python3 scripts/upload.py src/WavPlayer --board esp32
   ```

3. **開始播放**
   - 插入 SD 卡
   - 上電啟動
   - 按 **PAUSE** 按鈕開始播放

### 開機順序

```
ESP32 啟動
    ↓
載入 NVS 儲存狀態
    ↓
掃描 SD 卡 WAV 檔案
    ↓
初始化 I2S (APLL)
    ↓
恢復上次播放位置
    ↓
等待按鈕輸入
```

---

## 🔌 硬體連接

### SD 卡模組 (SPI)

| 功能 | ESP32 GPIO | 說明 |
| ---- | --- | --- |
| MISO | GPIO 19 | 數據輸出 |
| MOSI | GPIO 23 | 數據輸入 |
| SCK  | GPIO 18 | 時鐘 (20MHz) |
| CS | GPIO 5 | 片選 |
| VCC  | 3.3V | 電源 |
| GND  | GND | 接地 |

### I2S DAC

| 功能 | ESP32 GPIO | 說明 |
| --- | --- | --- |
| BCK | GPIO 4 | 位元時鐘 |
| WS (LRCK) | GPIO 15 | 左右聲道選擇 |
| DATA | GPIO 2 | 串列數據 |
| VIN | 3.3V or 5V | 依 DAC 規格  |
| GND | GND | 接地 |

### 控制按鈕

| 功能  | ESP32 GPIO | 接法 |
| ----- | --- | --- |
| VOL+  | GPIO 12 | 按鈕 → GPIO, 上拉 |
| VOL-  | GPIO 13 | 按鈕 → GPIO, 上拉 |
| PREV  | GPIO 14 | 按鈕 → GPIO, 上拉 |
| NEXT  | GPIO 27 | 按鈕 → GPIO, 上拉 |
| PAUSE | GPIO 26 | 按鈕 → GPIO, 上拉 |

> **Note**: 使用 `INPUT_PULLDOWN` 模式，按鈕接 3.3V

---

## 💻 Serial 指令參考

連接 Serial Monitor (460800 baud) 並輸入以下指令：

### 1. `mem` / `memory`

顯示記憶體使用狀態（含視覺化圖表）

```
mem

╔════════════════════════════════════════╗
║         Memory Status                  ║
╚════════════════════════════════════════╝
HEAP Memory:
  Total:      361400 bytes
  Used:       127416 bytes (35.3%)
  Free:       233984 bytes (64.7%)
  Min Free:   233000 bytes
  Usage: [███████░░░░░░░░░░░░░] 35.3%

PSRAM: Not available
```

**用途**: 檢查記憶體洩漏、確認系統穩定性

---

### 2. `status` / `s`

顯示播放器當前狀態

```
status

╔════════════════════════════════════════╗
║         Player Status                  ║
╚════════════════════════════════════════╝
State:   ▶️  Playing
Track:   3/8
File:    /music/song3.wav
Volume:  30%
Uptime:  1234 sec
```

**用途**: 快速查看播放資訊

---

### 3. `settings` / `config`

顯示系統設定與硬體配置

```
settings

╔════════════════════════════════════════╗
║         System Settings                ║
╚════════════════════════════════════════╝

📟 Hardware Configuration:
  I2S BCK:       GPIO 4
  I2S WS:        GPIO 15
  I2S DATA:      GPIO 2
  SD MISO:       GPIO 19
  SD MOSI:       GPIO 23
  SD SCK:        GPIO 18
  SD CS:         GPIO 5

🎮 Button Mapping:
  VOL+:          GPIO 12
  VOL-:          GPIO 13
  PREV:          GPIO 14
  NEXT:          GPIO 27
  PAUSE:         GPIO 26

🔧 System Parameters:
  Buffer Size:   8192 bytes
  Max Tracks:    32
  Sample Rate:   44100 Hz
  Bit Depth:     16-bit
  Channels:      Stereo (2)
  APLL:          Enabled
  SPI Speed:     20 MHz
  DMA Buffers:   8 x 1024

⏱️  Timing Settings:
  Debounce:      200 ms
  Long Press:    500 ms
  Double Click:  400 ms
  Fade Samples:  2048 (~46.4 ms)

🎵 Audio Features:
  ✓ Chunk-based WAV parsing
  ✓ Logarithmic volume curve
  ✓ Fade in/out transitions
  ✓ DMA buffer flush (anti-pop)
  ✓ NVS playback resume
  ✓ Hidden file filtering
```

**用途**: 確認硬體接線、查看系統參數

---

### 4. `cpu` / `tasks`

顯示 FreeRTOS 任務狀態與 CPU 負載

```
cpu

╔════════════════════════════════════════╗
║         Task Status (FreeRTOS)         ║
╚════════════════════════════════════════╝

Name          State   Prio    Stack   ID
──────────────────────────────────────────
AudioTask      B       2       1540    4
ButtonTask     B       1       1024    5
IDLE0          R       0       120     1
IDLE1          R       0       110     2
loopTask       X       1       2500    3
──────────────────────────────────────────

📊 State Legend:
  X: Running   (目前正在執行)
  B: Blocked   (等待中/閒置 - CPU 有空)
  R: Ready     (準備執行)
  S: Suspended (暫停)
  D: Deleted   (刪除中)

⚠️  Stack: 剩餘記憶體 (bytes)
  • <100  = 危險！可能 Stack Overflow
  • >500  = 安全
  • >2000 = 分配太多，可減少
```

**如何解讀**:

- `AudioTask` 和 `ButtonTask` 大部分時間應該是 `B` (Blocked) - 表示 CPU 有空閒
- `IDLE` 任務出現表示系統健康
- `Stack` 接近 0 表示危險，需增加任務堆疊大小

**用途**: 檢測 CPU 負載、除錯任務卡死問題

---

### 5. `nvs` / `read`

顯示 NVS Flash 儲存的狀態

```
nvs

╔════════════════════════════════════════╗
║         NVS Storage (Flash)            ║
╚════════════════════════════════════════╝

💾 Stored Preferences:
  Track Index:   2
  Track File:    /song3.wav
  Volume:        30%
  Position:      45.3s
  Was Playing:   No

📋 Current Runtime State:
  Track Index:   2
  Track File:    /song3.wav
  Volume:        30%
  Position:      45.3s
  State:         Paused

⚙️  NVS Operations:
  Auto-save triggers:
    - Track change
    - Volume change
    - Pause/Play toggle
    - Every 10 seconds (background)
  Manual commands:
    - 'save'   - Force save current state
    - 'clear'  - Clear NVS saved state
    - 'resume' - Reload saved state
```

**用途**:

- 確認斷點續播位置
- 檢查 NVS 是否正常儲存
- 對比 Flash 與 RAM 狀態

---

### 6. `tree` / `ls`

列出 SD 卡所有檔案

```
tree

📁 SD Card Structure:
═══════════════════════════════════════
📄 test.wav                       12.5 MB
📄 song2.wav                       8.3 MB
📄 music.wav                      15.2 MB
🔒 ._hidden.wav                   2.1 KB (hidden)
═══════════════════════════════════════
Total: 3 files, 0 dirs, 36.0 MB
```

**用途**: 快速檢視 SD 卡內容、確認檔案可見性

---

### 7. `cat <filename>`

顯示檔案資訊與內容

```
cat test.wav

📄 File: /test.wav
═══════════════════════════════════════
Size: 13107128 bytes

WAV Header:
  RIFF: RIFF
  File Size: 13107120
  WAVE: WAVE

Chunks:
  [0] fmt  - 16 bytes
      Format: 1 (1=PCM)
      Channels: 2
      Sample Rate: 44100 Hz
      Bit Depth: 16 bits
  [1] data - 13107084 bytes
```

**用途**:

- 檢查 WAV 檔案格式
- 除錯播放問題
- 查看 chunk 結構

---

### 8. `save`

手動儲存當前播放狀態到 NVS

```
save

✅ Playback state saved
```

**用途**:

- 在重要時刻手動備份狀態
- 測試 NVS 功能

---

### 9. `clear` / `reset`

清除 NVS 中儲存的所有資料

```
clear

🗑️  NVS cleared - all saved state deleted
```

**用途**:

- 重置播放狀態
- 解決 NVS 資料錯亂問題

---

### 10. `resume`

從 NVS 重新載入播放狀態

```
resume

🔄 Resuming from last session
   Track: 2, Volume: 30%, Position: 45.3s
✅ Playback state restored
```

**用途**:

- 恢復到上次儲存的狀態
- 測試斷點續播功能

---

---

### 11. `help` / `h` / `?`

顯示所有可用指令

```
help

╔════════════════════════════════════════╗
║         Available Commands             ║
╚════════════════════════════════════════╝
  mem, memory  - Show memory status
  status, s    - Show player status
  settings     - Show system configuration
  cpu, tasks   - Show FreeRTOS task status
  nvs, read    - Show NVS stored state
  tree, ls     - List SD card files
  cat <file>   - Show file info/content
  save         - Save playback state
  resume       - Restore playback state
  help, h, ?   - Show this help
```

---

## 🎮 按鈕控制

### VOL+ (GPIO 12)

- **單按**: 音量 +5%
- **長按**: 音量 +1% (持續，每 50ms)

### VOL- (GPIO 13)

- **單按**: 音量 -5%
- **長按**: 音量 -1% (持續，每 50ms)

### PREV (GPIO 14)

- **單按**: 上一首（重置播放位置）

### NEXT (GPIO 27)

- **單按**: 下一首（重置播放位置）

### PAUSE (GPIO 26)

- **單按**: 暫停/播放切換
- **雙擊** (< 400ms): 下一首

### PREV + NEXT (組合鍵)

- **長按** (0.5 秒): 切換循環模式 (Loop Single / Loop All)

---

## 🌟 進階功能

### 斷點續播

**功能**: 記住上次播放到哪個位置

**運作方式**:

1. 每 10 秒自動儲存播放位置到 NVS
2. 換曲、調音量、暫停時也會儲存
3. 斷電後重啟，自動恢復到上次位置

**示範**:

```
播放 song.wav 到 45.3 秒
    ↓
(突然斷電)
    ↓
重新開機
    ↓
🔄 Resuming from last session
   Track: 1, Volume: 30%, Position: 45.3s
    ↓
⏩ Resuming from 45.3s
    ↓
繼續播放！
```

**手動測試**:

```bash
# 1. 播放一段時間
(等待 20 秒)

# 2. 查看狀態
nvs
# 應該顯示 Position: ~20s

# 3. 重啟 ESP32
(拔電源再插回)

# 4. 確認恢復
# 應該看到自動載入訊息
```

---

### CPU 負載監控

**目的**: 實時監控 FreeRTOS 任務狀態

**健康指標**:

```
✅ 健康系統:
- AudioTask:  B (Blocked) - 大部分時間在等待
- ButtonTask: B (Blocked) - 大部分時間待命
- IDLE0/1:    R (Ready)   - 有機會執行

❌ 異常系統:
- AudioTask:  X (Running) - 持續滿載
- IDLE 消失 - CPU 100% 無空閒
- Stack < 100 - 即將崩潰
```

**除錯案例**:

```
問題: 切歌時卡頓

步驟 1: 檢查 CPU
cpu

發現: AudioTask Stack = 50 (太低!)

解決: 增加任務堆疊
xTaskCreate(..., 8192, ...) → xTaskCreate(..., 12288, ...)
```

---

### 記憶體監控

**目的**: 檢測記憶體洩漏

**正常模式**:

```
開機:  Free Heap: 250000 bytes
1小時: Free Heap: 235000 bytes (正常下降)
2小時: Free Heap: 233000 bytes (穩定)
3小時: Free Heap: 233000 bytes (穩定)
```

**異常模式** (記憶體洩漏):

```
開機:  Free Heap: 250000 bytes
1小時: Free Heap: 200000 bytes
2小時: Free Heap: 150000 bytes (持續下降!)
3小時: Free Heap:  50000 bytes (危險!)
```

**檢查方式**:

```bash
# 每小時執行一次
mem

# 記錄 Min Free Heap
# 如果持續下降 → 有記憶體洩漏
```

---

## 🐛 故障排除

### SD 卡無法讀取

**症狀**:

```
❌ SD Card failed!
```

**檢查清單**:

1. SD 卡是 FAT32 格式？
2. 接線正確？(MISO=19, MOSI=23, SCK=18, CS=5)
3. 電源足夠？(建議 5V/1A)
4. SD 卡速度？(建議 Class 10+)

**解決方式**:

```cpp
// 降低 SPI 速度測試
SD.begin(SD_CS, SPI, 10000000);  // 從 20MHz 降到 10MHz
```

---

### 沒有聲音

**檢查清單**:

1. DAC 接線正確？
2. DAC 有供電？
3. 音量是否 > 0？(`status` 查看)
4. 是否在暫停狀態？

**測試**:

```bash
status
# 確認:
# - State: Playing
# - Volume: > 0%

# 如果是 Paused
# 按 PAUSE 按鈕或重啟
```

---

### 播放卡頓

**可能原因**:

1. SD 卡太慢
2. WAV 檔案損壞
3. CPU 滿載

**診斷**:

```bash
# 1. 檢查 CPU
cpu
# AudioTask 應該大部分是 B (Blocked)

# 2. 檢查 WAV 檔案
cat song.wav
# 確認格式是 PCM, 44.1kHz, 16-bit

# 3. 使用更快的 SD 卡
# Class 10 或 UHS-I
```

---

### 換曲有爆音

**正常情況**: 應該已透過 DMA flush 消除

**如果還有爆音**:

```cpp
// 檢查 FADE_SAMPLES 設定
#define FADE_SAMPLES 2048  // 增加到 4096 試試

// 或降低 SPI 速度
SD.begin(SD_CS, SPI, 10000000);
```

---

### NVS 不儲存

**檢查**:

```bash
# 1. 測試儲存
save
✅ Playback state saved  # 應該看到這個

# 2. 查看內容
nvs
# 應該顯示儲存的數值

# 3. 重啟測試
(重啟 ESP32)
# 應該自動載入
```

**如果失敗**: Flash 可能損壞,重刷韌體試試

---

## 📚 參考資料

- [README.md](../README.md) - 專案概覽
- [NVS_EXPLAINED.md](NVS_EXPLAINED.md) - NVS 儲存機制
- [PRODUCTION_SUMMARY.md](PRODUCTION_SUMMARY.md) - 產品級功能總結
- [audio_converter_guide.md](audio_converter_guide.md) - 音訊轉換工具

---

## 🛠️ Serial File Manager (UART)

New in v3.2, you can manage files on the SD card directly over the USB Serial connection without removing the card.

### 1. Connectivity Test

- **Command**: `ping`
- **Response**: `pong`
- **Command**: `test_write`
- **Description**: Creates a test file `/test_serial.txt` to verify SD write permissions.

### 2. File Upload

- **Command**: `upload <remote_path> <size>`
- **Tools**: Use the provided python script for reliable transfer.
  ```bash
  python3 scripts/serial_upload.py /dev/cu.usbserial-XXXX local_file.mp3 /song.mp3
  ```
- **Note**: This uses a binary protocol and requires the dedicated script. Do not type this command manually.

---

---

## 🎓 進階閱讀

### FreeRTOS 任務設計

```cpp
// Core 0: 控制類任務
xTaskCreatePinnedToCore(
  buttonHandlerTask,  // 函數
  "ButtonTask",       // 名稱
  2048,               // Stack 大小
  NULL,               // 參數
  1,                  // 優先級 (低)
  &buttonTaskHandle,  // Handle
  0                   // Core 0
);

// Core 1: 音訊任務
xTaskCreatePinnedToCore(
  audioPlaybackTask,
  "AudioTask",
  8192,               // 需要更大 Stack
  NULL,
  2,                  // 優先級 (高)
  &audioTaskHandle,
  1                   // Core 1
);
```

### I2S APLL 配置

```cpp
i2s_config_t i2s_config = {
  .use_apll = true,        // 啟用 Audio PLL
  .sample_rate = 44100,    // 精確 44.1kHz
  .bits_per_sample = I2S_BITS_PER_SAMPLE_16BIT,
  .dma_buf_count = 8,      // 緩衝數量
  .dma_buf_len = 1024,     // 每個緩衝大小
};
```

### 音量曲線

```
線性 (舊):   0 - 10 - 20 - 30 - ... - 100
立方 (新):   Vol^3 曲線 (10% 音量時僅為原本的 0.1%)

人耳感知: 立方曲線在低音量下提供更精細的控制，適合高靈敏度耳機。
```

---

**版本**: v2.0.1 Production  
**最後更新**: 2026-01-01  
**狀態**: ✅ 穩定運行

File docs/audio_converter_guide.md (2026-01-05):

# Audio Converter - 使用指南

## 🎵 功能特色

### **支援格式**

**輸入格式：**

- MP3, M4A, AAC
- FLAC, WAV, OGG
- WMA, APE, ALAC
- 所有 FFmpeg 支援的音訊格式

**輸出格式：**

- **WAV** - 16-bit PCM, 44.1kHz (ESP32 播放用)
- **FLAC** - Lossless 無損, 44.1kHz (封存用)

### **最高音質設定**

#### WAV 格式

```
編碼: PCM 16-bit signed
取樣率: 44.1kHz
聲道: Stereo (2)
適用: ESP32-S3 HiFi-DAP 播放
```

#### FLAC 格式

```
編碼: FLAC lossless
取樣率: 44.1kHz
聲道: Stereo (2)
位元深度: 32-bit
壓縮等級: 8 (default, 0-12)
適用: 高保真封存、備份
```

## 📝 使用範例

### 基本用法

```bash
# 轉換為 WAV (預設)
python3 scripts/audio_converter.py song.mp3

# 轉換為 FLAC (無損)
python3 scripts/audio_converter.py song.mp3 --format flac

# 指定輸出檔名
python3 scripts/audio_converter.py song.mp3 -o output.wav
```

### 批次轉換

```bash
# 轉換資料夾內所有 MP3
python3 scripts/audio_converter.py *.mp3

# 轉換多個 FLAC 為 WAV
python3 scripts/audio_converter.py song1.flac song2.flac song3.flac --format wav

# 使用 verbose 查看詳細資訊
python3 scripts/audio_converter.py *.m4a -v
```

### 工作流程範例

#### 從 FLAC 封存轉為 ESP32 格式

```bash
# 1. 從 CD 擷取或下載 FLAC 無損檔案
# 2. 轉換為 ESP32 可播放的 WAV
python3 scripts/audio_converter.py album/*.flac --format wav

# 3. 將 WAV 複製到 SD 卡
cp *.wav /Volumes/SD_CARD/
```

#### 建立高品質封存

```bash
# 將各種格式統一為 FLAC 封存
python3 scripts/audio_converter.py *.mp3 *.m4a --format flac

# 結果：高品質無損 FLAC 檔案
```

## 🔧 命令列選項

```
usage: audio_converter.py [-h] [-f {wav,flac}] [-o OUTPUT] [-v] inputs [inputs ...]

ESP32-S3 HiFi-DAP Audio Converter with FLAC support

positional arguments:
  inputs                Input audio files

options:
  -h, --help            show this help message
  -f, --format {wav,flac}
                        Output format (default: wav)
  -o, --output OUTPUT   Output file path (single file only)
  -v, --verbose         Verbose FFmpeg output
```

## 📊 輸出資訊

### 範例輸出

```
ESP32-S3 HiFi-DAP Audio Converter
Maximum quality audio conversion

✓ ffmpeg version 6.0

🎵 Input: song.mp3
   Codec: mp3, Sample Rate: 44100Hz, Channels: 2
✓ Output: song.wav (12.45 MB)
   Format: WAV (16-bit PCM, 44.1kHz, Stereo)

Summary
Converted: 1/1 files
```

## ⚙️ 技術細節

### WAV 轉換參數

```bash
ffmpeg -i input.mp3 \
       -acodec pcm_s16le \    # 16-bit PCM
       -ar 44100 \            # 44.1kHz
       -ac 2 \                # Stereo
       -sample_fmt s16 \      # 16-bit signed
       output.wav
```

### FLAC 轉換參數

```bash
ffmpeg -i input.mp3 \
       -c:a flac \            # FLAC codec
       -ar 44100 \            # 44.1kHz
       -ac 2 \                # Stereo
       -compression_level 8 \ # Best balance
       -sample_fmt s32 \      # 32-bit signed
       output.flac
```

## 🎯 最佳實踐

### 1. **音樂庫管理**

```
原始檔案 (FLAC) → 封存保存
            ↓
        轉換為 WAV
            ↓
      複製到 SD 卡 → ESP32 播放
```

### 2. **檔案命名建議**

```bash
# 使用有意義的檔名
artist_-_song_title.wav

# 批次重命名範例
for f in *.wav; do
  mv "$f" "${f// /_}"  # 空格換底線
done
```

### 3. **SD 卡整理**

```
SD_CARD/
├── album1/
│   ├── 01_song1.wav
│   ├── 02_song2.wav
│   └── 03_song3.wav
└── album2/
    ├── 01_song1.wav
    └── 02_song2.wav
```

## ❓ 常見問題

### Q: WAV 檔案太大？

**A:** 使用 FLAC 格式封存，FLAC 約為 WAV 的 50-60% 大小且無損。

### Q: ESP32 可以播放 FLAC 嗎？

**A:** 目前只支援 WAV，未來可能加入 FLAC 解碼支援。

### Q: 如何批次轉換整個資料夾？

**A:**

```bash
# 使用 find + xargs
find music/ -name "*.mp3" -exec python3 scripts/audio_converter.py {} \;

# 或使用萬用字元
python3 scripts/audio_converter.py music/**/*.mp3
```

### Q: 轉換失敗怎麼辦？

**A:** 使用 `-v` 參數查看詳細錯誤：

```bash
python3 scripts/audio_converter.py song.mp3 -v
```

## 📦 依賴套件

```bash
# 安裝 FFmpeg (required)
brew install ffmpeg

# 安裝 Python 套件
pip install rich
```

## 🔗 相關資源

- FFmpeg 文件：https://ffmpeg.org/documentation.html
- FLAC 規格：https://xiph.org/flac/
- WAV 規格：https://en.wikipedia.org/wiki/WAV

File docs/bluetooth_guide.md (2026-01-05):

# Bluetooth Usage Guide

## Hybrid Bluetooth Architecture

This device functions as a **Dual-Mode Bluetooth Central**:

1.  **Scanner Mode (GAP)**: Searches for nearby Bluetooth speakers/headphones.
2.  **Source Mode (A2DP)**: Streams high-quality audio to the connected device.

## Step-by-Step Connection

### 1. Scan for Devices

Send the scan command. The device will pause audio (if playing) to dedicate radio resources to scanning.

```bash
> BT_SCAN
OK:Scanning... Please wait 15s
```

After 15 seconds, it returns a list:

```text
OK:2:[0]JBL Flip 5|A0:B1:C2:D3:E4:F5|-45,[1]Unknown|11:22:33:44:55:66|-80
```

### 2. Connect

Connect using the index from the scan list (e.g., `0` for JBL Flip 5).

```bash
> A2DP_CONNECT:0
INFO:Connecting to JBL Flip 5
OK:Connecting...
```

_Note: You can also connect by raw MAC address: `A2DP_CONNECT:A0:B1:C2:D3:E4:F5`_

### 3. Stream Audio

Once connected (Speaker usually beeps), playing any file will route audio to Bluetooth instead of the DAC.

```bash
> PLAY:test.wav
```

### 4. Disconnect

```bash
> A2DP_STOP
> BT_DISCONNECT
```

## Troubleshooting

- **Choppy Audio**:
  - Ensure the antenna is not obstructed.
  - WAV files > 16-bit/48kHz might exceed Bluetooth bandwidth; use standard CD quality (16/44.1).
  - Run `MEM` to check if PSRAM is full.
- **Scan Finds Nothing**:
  - Ensure the speaker is in **Pairing Mode**.
  - Some devices filter MAC addresses; check your speaker manual.

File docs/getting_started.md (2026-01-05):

# Getting Started Guide

## Prerequisites

### 1. Install Arduino CLI

```bash
# macOS
brew install arduino-cli
# Or download from https://arduino.github.io/arduino-cli/
```

### 2. Install ESP32 Platform

```bash
arduino-cli config init
arduino-cli config add board_manager.additional_urls https://raw.githubusercontent.com/espressif/arduino-esp32/gh-pages/package_esp32_index.json
arduino-cli core update-index
arduino-cli core install esp32:esp32
```

## Compilation & Upload

This project uses a Python script to wrap `arduino-cli` and `esptool`, providing a uniform build environment.

### 1. Compile

```bash
# Basic compile
python3 scripts/upload.py .

# Compile for a specific board variant (default is esp32)
python3 scripts/upload.py . --board esp32
```

### 2. Upload

The script automatically detects the serial port.

```bash
python3 scripts/upload.py .
```

If auto-detection fails, specify the port:

```bash
python3 scripts/upload.py . --port /dev/cu.usbserial-1234
```

### 3. Monitor

To view serial output and debug logs:

```bash
python3 scripts/monitor.py /dev/cu.usbserial-1234
# Default baud rate is 460800
```

## SD Card Setup

1.  Format a microSD card to **FAT32**.
2.  Copy `.wav` audio files to the root directory.
    - Format: 16-bit PCM WAV (44.1kHz / 48kHz recommended).
3.  Insert into the SD card slot.

## Troubleshooting

### "Plugin needed to handle lto object"

If you see linker errors related to LTO, it means your toolchain is mismatched.
**Fix**: The `scripts/upload.py` script automatically disables LTO flags if they cause issues. Ensure you are using the provided script, not raw `arduino-cli` commands.

### "No USB serial port found"

1.  Check USB cable (must support data).
2.  Install drivers for CP210x or CH340.
3.  On macOS, check `ls /dev/cu.*`.

### "SD Init Failed"

1.  Check if card is FAT32.
2.  Check SPI pin wiring (see `docs/hardware_reference.md`).

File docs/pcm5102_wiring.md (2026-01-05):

# PCM5102 DAC 接線指南 - TTGO T-Display V1.1

## 📌 引腳配置

### TTGO T-Display → PCM5102

| PCM5102 引腳 | TTGO GPIO | 功能說明 |
| --- | --- | --- |
| **BCK** | GPIO17 | I2S Bit Clock (位元時脈) |
| **DIN** | GPIO15 | I2S Data Out (音訊資料) |
| **LRCK** | GPIO2 | I2S Left/Right Clock (左右聲道選擇) |
| **GND** | GND | 接地 |
| **VIN** | 3V3 或 5V | 電源 (建議 3.3V) |
| **SCK** | 不接 | 系統時脈 (PCM5102 內建，可不接) |
| **FMT** | GND | 格式選擇 (接 GND = I2S 格式) |
| **XMT** | 3V3 | 靜音控制 (接 3V3 = 正常輸出) |

## ⚠️ 重要變更

### 引腳衝突修復

原本配置有衝突：

- ❌ **GPIO25** 同時用於 I2S_BCLK 和 SD_CS
- ❌ **GPIO26, GPIO27** 是 DAC 引腳，可能影響音質

### 新配置 (無衝突)

- ✅ **GPIO17** → I2S_BCLK (可用)
- ✅ **GPIO2** → I2S_LRC (可用，但不要用於按鈕)
- ✅ **GPIO15** → I2S_DOUT (可用)

## 📝 注意事項

1. **GPIO2 特殊性**

   - GPIO2 是 Strapping Pin
   - 開機時必須為 HIGH (上拉)
   - 不要接按鈕或負載

2. **電源連接**

   - **推薦**: VIN → 3V3 (乾淨電源)
   - **可選**: VIN → 5V (如果 DAC 模組支持)
   - 建議加 100µF 電容濾波

3. **音質優化**
   - GND 盡量粗短
   - 使用隔離電源
   - 遠離 WiFi/BT 模組

## 🔌 完整接線圖

```
TTGO T-Display V1.1          PCM5102 DAC Module
┌─────────────────┐         ┌──────────────────┐
│                 │         │                  │
│  GPIO17    ────────────────→ BCK             │
│  GPIO15    ────────────────→ DIN             │
│  GPIO2     ────────────────→ LRCK            │
│  GND       ────────────────→ GND             │
│  3V3       ────────────────→ VIN             │
│                 │         │                  │
│                 │         │  GND ← FMT       │
│                 │         │  3V3 ← XMT       │
│                 │         │                  │
└─────────────────┘         └──────────────────┘
                                     │
                                     ↓
                              3.5mm 音訊輸出
```

## ✅ 功能配置

- ✅ I2S PCM5102 輸出
- ✅ SD 卡播放
- ✅ TFT 顯示
- ❌ 藍牙 A2DP (已停用)

## 🧪 測試步驟

1. 上傳韌體

```bash
python3 scripts/upload.py --baud 460800
```

2. 檢查序列輸出

```
I2S initialized successfully
Audio player initialized successfully
```

3. 播放測試

```
PLAY_CURRENT  # 播放當前曲目
```

4. 確認音訊輸出

- 檢查 PCM5102 LED (如果有)
- 連接耳機/喇叭測試

## 🔧 故障排除

### 無聲音

- 檢查接線
- 確認 FMT 接 GND
- 確認 XMT 接 3V3 (不靜音)

### 雜音

- 改善電源品質
- 檢查 GND 連接
- 遠離干擾源

### I2S 初始化失敗

- 檢查引腳配置
- 確認沒有引腳衝突
- 查看序列輸出錯誤訊息

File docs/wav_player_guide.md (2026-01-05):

# [DEPRECATED] WAV Player Usage Guide

> **⚠️ NOTE**: This guide is outdated. Please refer to [USER_GUIDE.md](../docs/USER_GUIDE.md) and [README.md](../README.md) for the latest instructions on MP3/WAV playback, controls, and features.

## Quick Start

### 1. Prepare Your WAV File

Create a test WAV file using ffmpeg:

```bash
# Generate a 10-second 1kHz sine wave test tone
ffmpeg -f lavfi -i "sine=frequency=1000:duration=10" -ar 44100 -ac 2 -c:a pcm_s16le test2.wav

# OR convert any audio file to the correct format
ffmpeg -i your_song.mp3 -ar 44100 -ac 2 -c:a pcm_s16le test2.wav
```

Copy `test2.wav` to the **root directory** of your FAT32-formatted SD card.

### 2. Hardware Connections

**SD Card Module (SPI):**

```
SD Card    →  ESP32
MISO       →  GPIO36 (Input Only)
MOSI       →  GPIO32
SCK        →  GPIO33
CS         →  GPIO25
VCC        →  3.3V
GND        →  GND
```

**PCM5102 DAC Module (I2S):**

```
PCM5102    →  ESP32
BCK        →  GPIO26
LRCK/WS    →  GPIO27
DIN        →  GPIO22
VIN        →  5V (or 3.3V)
GND        →  GND
AGND       →  GND (Important!)
```

**Audio Output:**

```
PCM5102    →  Output Device
LROUT      →  Left channel
ROUT       →  Right channel
AGND       →  Ground
```

Connect to:

- 🎧 Headphones (via 3.5mm jack)
- 🔊 Powered speakers
- 🎸 Amplifier AUX input

### 3. Upload Firmware

Using Arduino CLI:

```bash
# Compile
arduino-cli compile --fqbn esp32:esp32:esp32s3 src/WavPlayer

# Upload (adjust port as needed)
arduino-cli upload --fqbn esp32:esp32:esp32s3 -p /dev/cu.usbserial-* src/WavPlayer

# Monitor output
arduino-cli monitor -p /dev/cu.usbserial-* -c baudrate=460800
```

Or use Arduino IDE:

1. Open `src/WavPlayer/WavPlayer.ino`
2. Select your ESP32 board
3. Click Upload
4. Open Serial Monitor at 460800 baud

### 4. Expected Output

Serial Monitor will show:

```
=== WAV Player with PCM5102 I2S DAC ===

Initializing SD card...
  MISO: GPIO36 (Input Only)
  MOSI: GPIO32
  SCK:  GPIO33
  CS:   GPIO25
✅ SD Card initialized

Opening /test2.wav...

📊 WAV File Info:
  Sample Rate: 44100 Hz
  Channels: 2 (Stereo)
  Bits per Sample: 16
  Audio Format: PCM
  Data Size: 1764000 bytes (1.68 MB)
  Duration: 10.0 seconds

Initializing I2S...
  BCK:  GPIO26
  LRCK: GPIO27
  DIN:  GPIO22
✅ I2S initialized

🎵 Starting playback...

Playing... [▓▓▓▓▓▓▓▓▓░░░░░░░░░░░] 47%
```

**Audio will play continuously in a loop!** 🔁

## Troubleshooting

### No Audio?

1. **Check DAC wiring**

   - Verify BCK, LRCK, DIN are correctly connected
   - Ensure VIN has stable power (5V recommended)
   - **IMPORTANT**: Connect AGND to GND!

2. **Check output device**

   - Use powered speakers or amplifier (DAC output is line-level)
   - If using headphones, they may need amplification
   - Test with different output device

3. **Check file format**

   ```bash
   # Verify WAV format
   ffprobe test2.wav
   ```

   Must be: PCM, 16-bit, 44.1kHz, Stereo

4. **Try different sample rate**
   ```bash
   # Create 48kHz version
   ffmpeg -i test2.wav -ar 48000 test2_48k.wav
   ```

### SD Card Not Detected?

1. **Format as FAT32**

   - Use SD Card Formatter tool
   - Maximum 32GB for FAT32

2. **Check wiring**

   - GPIO36 must be MISO (it's input-only, perfect for this)
   - Double-check all SPI connections

3. **Try slower SPI speed**
   In WavPlayer.ino, change:
   ```cpp
   SD.begin(SD_CS, SPI, 10000000)  // 10MHz
   ```
   to:
   ```cpp
   SD.begin(SD_CS, SPI, 4000000)   // 4MHz
   ```

### File Not Found?

- Ensure file is named exactly `test2.wav` (lowercase)
- Place in SD card root directory (not in a folder)
- Verify SD card is properly inserted

### Choppy Audio?

This shouldn't happen with the 8KB buffer, but if it does:

- Increase `BUFFER_SIZE` in code (try 16384)
- Use Arduino IDE with "Huge App" partition scheme
- Check SD card quality (use Class 10 or better)

## Advanced Configuration

### Change File Name

Edit line in `WavPlayer.ino`:

```cpp
if (!openWAVFile("/test2.wav")) {
```

Change to your filename, e.g.:

```cpp
if (!openWAVFile("/music.wav")) {
```

### Change I2S Pins

Edit the pin definitions:

```cpp
#define I2S_BCK   26    // Change to your BCK pin
#define I2S_WS    27    // Change to your WS pin
#define I2S_DATA  22    // Change to your DATA pin
```

### Disable Loop Playback

In the `loop()` function, replace the restart code with:

```cpp
} else {
  // Stop playback
  Serial.println("\n\n✅ Playback finished!");
  while(1) delay(1000);  // Stop here
}
```

## Technical Details

- **Buffer Size**: 8KB DMA buffer for smooth playback
- **I2S Mode**: Master TX, I2S format
- **DMA Buffers**: 8 buffers × 1024 bytes
- **Supported Formats**: PCM WAV, 16-bit, Mono/Stereo
- **Auto Sample Rate**: Reads from WAV header (supports 44.1kHz, 48kHz, etc.)
- **Memory Usage**: ~10KB RAM

## PCM5102 Jumper Settings

Your PCM5102 module has jumpers (H1L/H2L/H3L). **Default settings are fine!**

- H1L: Filter Select (Normal latency)
- H2L: De-emphasis (Off)
- H3L: Soft Mute (Unmuted)

**Don't change these unless you know what you're doing!**

## What's Next?

This player is a foundation for:

- 🎮 Adding button controls (play/pause/next/previous)
- 📁 Playing multiple files from a playlist
- 📱 Adding OLED/TFT display
- 📶 Bluetooth control
- 🎛️ Volume control
- 🎚️ EQ/effects processing

Enjoy your ESP32 Hi-Fi audio player! 🎶

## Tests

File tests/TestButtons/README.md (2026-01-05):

# Button Test Guide

## 📌 按鈕接線圖

基於您的 ESP32-WROOM 開發板：

```
按鈕      GPIO    接線方式
─────────────────────────────
VOL+  →  GPIO12  →  按鈕 → 3.3V
VOL-  →  GPIO13  →  按鈕 → 3.3V
PREV  →  GPIO14  →  按鈕 → 3.3V
NEXT  →  GPIO27  →  按鈕 → 3.3V
```

### 實體接線

每個按鈕需要：

- 一端接到對應的 GPIO
- 另一端接到 3.3V

**不需要外接電阻！** 程式已啟用內部下拉電阻。

### 在開發板上的位置（左側針腳）

```
[ESP32-WROOM 左側]
    ...
    GPIO27  ← NEXT 按鈕
    GPIO26
    GPIO25
    GPIO14  ← PREV 按鈕
    GPIO12  ← VOL+ 按鈕
    GPIO13  ← VOL- 按鈕
    ...
```

## 🚫 避開的腳位

**已使用（不要碰）：**

- SD 卡：GPIO19, GPIO23, GPIO18, GPIO5
- I2S DAC：GPIO4, GPIO15, GPIO2

## 🧪 測試步驟

### 1. 上傳測試程式

```bash
python3 scripts/upload.py tests/TestButtons --board esp32 --no-build
```

### 2. 連接按鈕

最簡單的測試方式：

- 用杜邦線，一端接 GPIO，另一端手動碰觸 3.3V（快速測試）
- 或焊接實際按鈕

### 3. 觀察 Serial Monitor

預期輸出：

```
╔════════════════════════════════════════╗
║   ESP32 Button Test - 4 Buttons        ║
╚════════════════════════════════════════╝

Button Configuration:
┌────────┬────────┬──────────────────┐
│ Button │  GPIO  │   Connection     │
├────────┼────────┼──────────────────┤
│ VOL+   │  12    │ GPIO12 ↔ 3.3V   │
│ VOL-   │  13    │ GPIO13 ↔ 3.3V   │
│ PREV   │  14    │ GPIO14 ↔ 3.3V   │
│ NEXT   │  27    │ GPIO27 ↔ 3.3V   │
└────────┴────────┴──────────────────┘

🎮 Button test ready!
Press any button to test...
```

### 4. 按下按鈕

按下 VOL+ 時會顯示：

```
╔════════════════════════════════════════╗
║ 🔘 Button Pressed: VOL+                ║
╠════════════════════════════════════════╣
║ GPIO: 12                               ║
║ Press Count: 1                         ║
╚════════════════════════════════════════╝
🔊 Action: Increase Volume
   Volume: [███████████░░░░░░░░] 55%
```

## 🎛️ 功能說明

### VOL+ / VOL- 按鈕

- 每次按下改變音量 ±5%
- 範圍：0-100%
- 視覺化音量條顯示

### PREV / NEXT 按鈕

- 模擬切換曲目（test1.wav, test2.wav, ...）
- 顯示當前播放曲目
- 循環播放（到最後會回到第一首）

### 防彈跳

- 自動 50ms 防彈跳處理
- 不會因為按鈕抖動而重複觸發

### 狀態監控

- 每 5 秒顯示按鈕狀態摘要
- 顯示每個按鈕的按壓次數
- 系統運行時間

## ✅ 測試檢查清單

- [ ] VOL+ 按鈕能觸發
- [ ] VOL- 按鈕能觸發
- [ ] PREV 按鈕能觸發
- [ ] NEXT 按鈕能觸發
- [ ] 音量條正常顯示
- [ ] 曲目切換正常顯示
- [ ] 沒有重複觸發（防彈跳正常）

## 🔧 故障排除

### 按鈕按下沒反應

1. 檢查接線（GPIO 正確？3.3V 正確？）
2. 確認按鈕本身是好的
3. 檢查 Serial Monitor 的狀態欄（每 5 秒更新）

### 按一次觸發多次

1. 按鈕品質問題（更換按鈕）
2. 增加 DEBOUNCE_MS 值（程式碼第 18 行）

### GPIO 衝突

如果這些 GPIO 有問題，可改用：

- 備選：GPIO21, GPIO22, GPIO32, GPIO33

## 📸 接線參考

ESP32 Pinout

按鈕接在**左側**的 GPIO12/13/14/27，方便接線且不衝突！

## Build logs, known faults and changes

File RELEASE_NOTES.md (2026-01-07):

# Release Notes - v3.1.0 "Dynamic Loudness" 🎵

## 🚀 Major Updates

### 1. Dynamic Loudness Compensation (Fletcher-Munson)

Implementing "Product-Grade" DSP logic that adapts real-time to your listening volume:

- **Low Volume (<30%)**: **+8dB Bass / +4dB Treble**. Maintains deep, rich sound even at night.
- **High Volume (>80%)**: **+2dB Bass / +1dB Treble**. Tights up the sound for high-SPL listening without booming.
- **Smooth Transition**: EQ curve interpolates linearly between volume points.

### 2. Refined EQ Profile (Audiophile V3)

- **Treble Cutoff**: Moved from **750Hz** to **3000Hz (3kHz)**.
  - _Why?_ To strictly target "Air" and "Clarity" while preserving the natural body of vocals (1kHz-2kHz).
- **Bass Cutoff**: Maintained at **100Hz** for solid fundamental impact.

### 3. Audiophile Sound Engine (Retained)

- **💎 TPDF Dithering**: Active.
- **🛡️ Anti-Clipping**: 0.7x Headroom Scaler.
- **⚡ PCM5102A Optimization**: Internal PLL mode (SCK->GND).

### 4. Hybrid Audio Core

Robust playback support powered by `BackgroundAudio`:

- **Universal Playback**: Seamlessly handles **WAV** (16-bit PCM) and **MP3** files in the same playlist.
- **Smart Parsing**: Robust chunk-based WAV parser prevents crashes on metadata-heavy files.

### 3. Professional Controls

- **Loop Modes**: Toggle between "Loop All" and "Loop Single" (Hold PREV+NEXT).
- **Cubic Volume**: `vol^3` curve for precise low-volume adjustment.
- **Persistence**: Remembers Track, Volume, Position, and Loop Mode across reboots.

## 🛠️ Technical Improvements

- **FreeRTOS Architecture**:
  - **Core 0**: Button ISRs, UI Logic, NVS Storage.
  - **Core 1**: Audio Decoding, DSP Pipeline, I2S DMA.
- **Memory Safety**: Replaced all `String` usage with fixed `char` arrays to prevent heap fragmentation.
- **NVS Optimization**: Only saves state on significant events or auto-save intervals to reduce flash wear.

## 📋 Recommended Hardware

| Component | Note |
| :--- | :--- |
| **DAC** | **PCM5102A** (Connect SCK to GND for PLL mode) |
| **Power** | Add **100uF + 0.1uF** caps near DAC VCC |
| **SD** | Class 10 card (formatted FAT32) |

---

_Verified on ESP32-S3 HiFi-DAP Hardware._

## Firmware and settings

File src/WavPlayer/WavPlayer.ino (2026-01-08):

/**
 * Production-Grade Multi-Core WAV Player - Refactored
 * FreeRTOS + Professional Audio Quality
 * 
 * Key Features:
 *   - Modular architecture
 *   - Configurable bit depth (16/24/32-bit)
 *   - Robust chunk-based WAV parsing
 *   - APLL for precise audio clock
 *   - Logarithmic volume control
 *   - Fade in/out (no pop noise)
 *   - NVS playback position resume
 */

#include <SPI.h>
#include <SD.h>
#include <ESP32I2SAudio.h>
#include <BackgroundAudioMP3.h>
#include <BackgroundAudioWAV.h>

// Include all module headers
#include "Config.h"
#include "AudioProcessor.h"
#include "PlaylistManager.h"
#include "ButtonHandler.h"
#include "SerialCommands.h"

// ========== Global State Definitions ==========
Preferences prefs;
SemaphoreHandle_t stateMutex;

volatile PlaybackState playbackState = STATE_PAUSED;
volatile int currentVolume = 20;
volatile int currentTrack = 0;
volatile bool trackChanged = false;
volatile uint32_t currentPosition = 0;
volatile uint32_t totalDataSize = 0;
volatile LoopMode loopMode = LOOP_ALL;

char playlist[MAX_TRACKS][MAX_FILENAME];
int playlistSize = 0;

volatile bool isReceivingFile = false;
File uploadFile;
size_t uploadRemaining = 0;
unsigned long lastUploadActivity = 0;

volatile AudioFormat currentFormat = FORMAT_UNKNOWN;

volatile bool btnPressed[5] = {false, false, false, false, false};
volatile unsigned long lastInterruptTime[5] = {0, 0, 0, 0, 0};
volatile bool btnLongPress[2] = {false, false};

TaskHandle_t audioTaskHandle = NULL;
TaskHandle_t buttonTaskHandle = NULL;

uint8_t audioBuffer[BUFFER_SIZE];

// BackgroundAudio Objects
BackgroundAudioMP3 *mp3Decoder = NULL;
BackgroundAudioWAV *wavDecoder = NULL;
File audioFile;

// ========== Audio Playback Task (Core 1) ==========
void audioPlaybackTask(void* parameter) {
  Serial.printf("🎵 Audio Task started on Core %d\n", xPortGetCoreID());
  
  bool needNewFile = true;
  uint8_t buffer[512];
  
  // Initialize I2S Audio Output
  if (!audioOut) {
    audioOut = new AudioOutputWithEQ(I2S_BCK, I2S_WS, I2S_DATA);
    Serial.println("✅ AudioOutputWithEQ initialized");
  }

  while (true) {
    if (playlistSize == 0) {
      vTaskDelay(100 / portTICK_PERIOD_MS);
      continue;
    }
    
    // === Track Change / Cleanup ===
    if (trackChanged) {
      trackChanged = false;
      
      if (mp3Decoder) { delete mp3Decoder; mp3Decoder = NULL; }
      if (wavDecoder) { delete wavDecoder; wavDecoder = NULL; }
      if (audioOut) { 
          audioOut->end();
          delete audioOut; 
          audioOut = NULL; 
      } 
      if (audioFile) { audioFile.close(); }
      
      currentPosition = 0;
      needNewFile = true;
      savePlaybackState();
    }
    
    // === Load New File ===
    if (needNewFile) {
      if (audioFile) audioFile.close();
      if (mp3Decoder) { delete mp3Decoder; mp3Decoder = NULL; }
      if (wavDecoder) { delete wavDecoder; wavDecoder = NULL; }
      if (audioOut) { 
          audioOut->end();
          delete audioOut; 
          audioOut = NULL; 
      } 
      
      if (audioOut == NULL) {
          audioOut = new AudioOutputWithEQ(I2S_BCK, I2S_WS, I2S_DATA);
          audioOut->begin();
          
          float gain = pow((float)currentVolume / 20.0f, 3.0f);
          audioOut->updateLoudness(currentVolume); 
      }

      xSemaphoreTake(stateMutex, portMAX_DELAY);
      int track = currentTrack;
      xSemaphoreGive(stateMutex);
      
      Serial.printf("\n▶️  Playing: %s\n", playlist[track]);
      currentFormat = detectAudioFormat(playlist[track]);
      
      audioFile = SD.open(playlist[track], FILE_READ);
      if (!audioFile) {
        Serial.printf("❌ Failed to open: %s\n", playlist[track]);
        currentTrack = (currentTrack + 1) % playlistSize;
        trackChanged = true;
        vTaskDelay(500 / portTICK_PERIOD_MS);
        continue;
      }
      
      if (currentFormat == FORMAT_MP3) {
        mp3Decoder = new BackgroundAudioMP3(*audioOut);
        mp3Decoder->begin();
        Serial.println("   Format: MP3");
      } else if (currentFormat == FORMAT_WAV) {
        wavDecoder = new BackgroundAudioWAV(*audioOut);
        wavDecoder->begin();
        Serial.println("   Format: WAV");
      } else {
        Serial.println("❌ Unknown format");
        audioFile.close();
        currentTrack = (currentTrack + 1) % playlistSize;
        trackChanged = true;
        continue;
      }
      
      needNewFile = false;
    }
    
    // === Playback State Handling ===
    xSemaphoreTake(stateMutex, portMAX_DELAY);
    PlaybackState state = playbackState;
    xSemaphoreGive(stateMutex);
    
    if (state == STATE_PAUSED || state == STATE_STOPPED) {
      vTaskDelay(100 / portTICK_PERIOD_MS);
      continue;
    }
    
    // === Data Feed Loop ===
    if (audioFile && (mp3Decoder || wavDecoder)) {
      static int lastAppliedVolume = -1;
      
      if (currentVolume != lastAppliedVolume) {
          audioOut->updateLoudness(currentVolume);
          lastAppliedVolume = currentVolume;
      }

      float lin_vol = currentVolume / 100.0f;
      float vol = lin_vol * lin_vol * lin_vol; 
      
      if (mp3Decoder) mp3Decoder->setGain(vol);
      if (wavDecoder) wavDecoder->setGain(vol);
      
      bool readyForData = false;
      if (mp3Decoder) readyForData = (mp3Decoder->availableForWrite() > sizeof(buffer));
      if (wavDecoder) readyForData = (wavDecoder->availableForWrite() > sizeof(buffer));
      
      if (readyForData) {
        int bytesRead = audioFile.read(buffer, sizeof(buffer));
        if (bytesRead > 0) {
          if (mp3Decoder) mp3Decoder->write(buffer, bytesRead);
          if (wavDecoder) wavDecoder->write(buffer, bytesRead);
          currentPosition += bytesRead;
        } else {
          Serial.println("✅ Track finished");
          audioFile.close();
          
          xSemaphoreTake(stateMutex, portMAX_DELAY);
          if (loopMode == LOOP_SINGLE) {
             trackChanged = true;
          } else if (loopMode == LOOP_ALL) {
             currentTrack = (currentTrack + 1) % playlistSize;
             trackChanged = true;
          } else {
             currentTrack++;
             if (currentTrack >= playlistSize) {
               currentTrack = 0;
               playbackState = STATE_STOPPED;
               trackChanged = true;
             } else {
               trackChanged = true;
             }
          }
           xSemaphoreGive(stateMutex);
        }
      } else {
        vTaskDelay(2 / portTICK_PERIOD_MS);
      }
    } else {
       vTaskDelay(10 / portTICK_PERIOD_MS);
    }
  }
}

// ========== Setup ==========
void setup() {
  Serial.setRxBufferSize(8192);
  Serial.begin(460800);
  delay(1000);
  
  Serial.println("\n╔════════════════════════════════════════╗");
  Serial.println("║  Production-Grade WAV Player (Modular) ║");
  Serial.println("╚════════════════════════════════════════╝\n");
  
  stateMutex = xSemaphoreCreateMutex();
  
  loadPlaybackState();
  
  loopMode = LOOP_ALL;
  Serial.println("🔁 Loop mode forced to: All (Loop playlist)");
  
  Serial.println("💾 Initializing SD card...");
  SPI.begin(SD_SCK, SD_MISO, SD_MOSI, SD_CS);
  if (!SD.begin(SD_CS, SPI, 10000000)) {
    Serial.println("❌ SD Card failed!");
    while (1) delay(1000);
  }
  Serial.println("✅ SD Card OK\n");
  
  scanPlaylist();
  if (playlistSize == 0) {
    Serial.println("❌ No WAV files found!");
    while (1) delay(1000);
  }
  
  if (currentTrack >= playlistSize) {
    currentTrack = 0;
  }
  
  File testFile = SD.open(playlist[currentTrack], FILE_READ);
  if (!testFile) {
    Serial.printf("⚠️  Saved track not found: %s\n", playlist[currentTrack]);
    Serial.println("   Resetting to first track");
    currentTrack = 0;
    currentPosition = 0;
    savePlaybackState();
  } else {
    testFile.close();
  }
  
  Serial.println("\n🔊 Audio System Initializing...");
  Serial.println("✅ Audio System Ready\n");
  
  EVENT_LOG("Initializing buttons");
  Serial.println("🎮 Initializing buttons...");
  
  pinMode(BTN_VOL_UP, INPUT_PULLDOWN);
  pinMode(BTN_VOL_DOWN, INPUT_PULLDOWN);
  pinMode(BTN_PREV, INPUT_PULLDOWN);
  pinMode(BTN_NEXT, INPUT_PULLDOWN);
  pinMode(BTN_PAUSE, INPUT_PULLDOWN);
  
  delay(100);
  
  attachInterrupt(digitalPinToInterrupt(BTN_VOL_UP), isr_vol_up, RISING);
  attachInterrupt(digitalPinToInterrupt(BTN_VOL_DOWN), isr_vol_down, RISING);
  attachInterrupt(digitalPinToInterrupt(BTN_PREV), isr_prev, RISING);
  attachInterrupt(digitalPinToInterrupt(BTN_NEXT), isr_next, RISING);
  attachInterrupt(digitalPinToInterrupt(BTN_PAUSE), isr_pause, RISING);
  
  Serial.println("✅ Buttons OK\n");
  
  Serial.println("🚀 Starting FreeRTOS tasks...");
  
  xTaskCreatePinnedToCore(
    audioPlaybackTask,
    "AudioTask",
    16384,
    NULL,
    2,
    &audioTaskHandle,
    1
  );
  
  xTaskCreatePinnedToCore(
    buttonHandlerTask,
    "ButtonTask",
    4096,
    NULL,
    1,
    &buttonTaskHandle,
    0
  );
  
  Serial.println("✅ Tasks started\n");
  Serial.println("═══════════════════════════════════════");
  Serial.println("Ready! Type 'help' for commands\n");
  
  playbackState = STATE_PLAYING;
}

// ========== Loop ==========
void loop() {
  handleSerialCommand();
  handleFileUpload();
  vTaskDelay(10 / portTICK_PERIOD_MS);
}

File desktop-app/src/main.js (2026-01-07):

const { app, BrowserWindow, ipcMain } = require('electron');
const path = require('path');
const { SerialPort } = require('serialport');
const { ReadlineParser } = require('@serialport/parser-readline');

let mainWindow;
let port;
let parser;

// Configuration
const BAUD_RATE = 460800;

function createWindow() {
    mainWindow = new BrowserWindow({
        width: 1000,
        height: 800,
        webPreferences: {
            preload: path.join(__dirname, 'preload.js'),
            nodeIntegration: false,
            contextIsolation: true
        },
        titleBarStyle: 'hiddenInset', // Mac-style
        backgroundColor: '#1E1E1E'
    });

    mainWindow.loadFile(path.join(__dirname, 'index.html'));
}

app.whenReady().then(() => {
    createWindow();

    app.on('activate', () => {
        if (BrowserWindow.getAllWindows().length === 0) createWindow();
    });
});

app.on('window-all-closed', () => {
    if (process.platform !== 'darwin') app.quit();
});

// ========== SERIAL PORT MANAGER ==========

ipcMain.handle('list-ports', async () => {
    try {
        const ports = await SerialPort.list();
        return ports;
    } catch (err) {
        console.error("Error listing ports:", err);
        return [];
    }
});

ipcMain.handle('connect', async (event, path) => {
    if (port && port.isOpen) {
        port.close();
    }

    try {
        port = new SerialPort({ path: path, baudRate: BAUD_RATE });
        parser = port.pipe(new ReadlineParser({ delimiter: '\n' }));

        port.on('open', () => {
            console.log(`Connected to ${path}`);
            mainWindow.webContents.send('serial-status', 'connected');
        });

        port.on('error', (err) => {
            console.error('Serial Error:', err);
            mainWindow.webContents.send('serial-status', 'error');
        });

        port.on('close', () => {
            console.log('Port Closed');
            mainWindow.webContents.send('serial-status', 'disconnected');
        });

        parser.on('data', (line) => {
            try {
                // Try parsing JSON
                const json = JSON.parse(line.trim());
                mainWindow.webContents.send('serial-data', json);
            } catch (e) {
                // Forward raw logs if not JSON
                console.log("Raw:", line);
                mainWindow.webContents.send('serial-log', line);
            }
        });

        return true;
    } catch (err) {
        console.error("Connection Failed:", err);
        return false;
    }
});

ipcMain.handle('send-command', (event, cmd) => {
    if (port && port.isOpen) {
        // Clear input buffer mainly for clean responses
        port.flush();
        port.write(cmd + '\n');
        console.log("Sent:", cmd);
    }
});

ipcMain.handle('upload-file', async (event, localPath, remotePath) => {
    if (!port || !port.isOpen) return { success: false, message: "Not connected" };

    const fs = require('fs');

    try {
        const stats = fs.statSync(localPath);
        const fileSize = stats.size;

        console.log(`Starting upload: ${localPath} -> ${remotePath} (${fileSize} bytes)`);

        // 1. Send Upload Command
        // We assume remotePath starts with /
        port.write(`upload ${remotePath} ${fileSize}\n`);

        // 2. Wait for READY (Blocking-ish for simplicity in this async handler)
        // In a real app we might use a proper state machine, but here we'll wait for the "serial-data" 
        // listener to flip a flag or just wait a bit and assume ready if no error? 
        // Actually, we can pause the continuous parser?
        // Better: Wait for a specific single-line response "READY"

        await new Promise(resolve => setTimeout(resolve, 500)); // Give ESP32 time to prep
        // Note: Ideally we should listen for "READY", but for MVP we rely on the 
        // fact that ESP32 handles this quickly. 
        // Let's add a small check if possible, but reading specific lines from a shared Serial stream 
        // that is also piping to a global parser is tricky. 
        // SAFE BET: Just wait 500ms. The ESP32 is fast.

        const fd = fs.openSync(localPath, 'r');
        // 8KB chunks with aggressive flow control for stability
        const CHUNK_SIZE = 8192;
        const buffer = Buffer.alloc(CHUNK_SIZE);
        let bytesRead = 0;
        let totalSent = 0;
        let chunkCount = 0;

        while ((bytesRead = fs.readSync(fd, buffer, 0, CHUNK_SIZE, null)) !== 0) {
            // Write chunk
            port.write(buffer.subarray(0, bytesRead));
            totalSent += bytesRead;
            chunkCount++;

            // Progress Update
            const progress = Math.round((totalSent / fileSize) * 100);
            mainWindow.webContents.send('upload-progress', progress);

            // Aggressive delay for SD card write time
            await new Promise(r => setTimeout(r, 150));

            // Every 5 chunks (40KB), pause longer to ensure SD buffer is fully written
            if (chunkCount % 5 === 0) {
                await new Promise(r => setTimeout(r, 500));
            }
        }

        fs.closeSync(fd);
        console.log("Upload Complete. Waiting for ESP32 to finish SD write...");

        // Wait longer for ESP32 to complete SD card operations
        await new Promise(r => setTimeout(r, 2000));

        // 🔄 Auto-refresh file list after upload
        console.log("Upload successful! Refreshing file list...");
        if (port && port.isOpen) {
            // Give ESP32 more time to stabilize
            await new Promise(r => setTimeout(r, 500));
            port.write('list_json\n');
        }

        return { success: true };

    } catch (err) {
        console.error("Upload Failed:", err);
        return { success: false, message: err.message };
    }
});

// File Operations
ipcMain.handle('delete-file', async (event, path) => {
    if (!port || !port.isOpen) return { success: false };
    port.write(`delete ${path}\n`);
    // Optimistic success, or wait for "SUCCESS" message in parser?
    // For now, let's just wait a moment.
    await new Promise(r => setTimeout(r, 200));
    return { success: true };
});

ipcMain.handle('rename-file', async (event, oldPath, newPath) => {
    if (!port || !port.isOpen) return { success: false };
    port.write(`rename ${oldPath} ${newPath}\n`);
    await new Promise(r => setTimeout(r, 200));
    return { success: true };
});

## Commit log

2025-12-30 Initial commit: Add comprehensive project documentation
    - Add detailed README.md with project proposal
    - Include hardware architecture and BOM
    - Add development roadmap (Phase 1-3)
    - Add MIT License
    - Add .gitignore for PlatformIO/ESP32 project
2026-01-05 feat(audiophile): V3.0.0 Release - TPDF Dither, Float EQ, PCM5102A
    [partitions.csv]
2026-01-07 Update README with Loop Control and Startup Splash features
    [walkman.scad, walkman_detailed.scad, walkman_pcb_fit.scad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]
2026-01-08 refactor: Modularize WavPlayer and add bit depth control
    Major Changes:
    - Split WavPlayer.ino (1688→350 lines) into modular components
    - Add 16/24/32-bit I2S output support
    - Update README with new architecture
    Components:
    - Config.h: Global configuration
    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
